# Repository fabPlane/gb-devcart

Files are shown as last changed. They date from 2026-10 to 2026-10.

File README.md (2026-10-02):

# GB DEVCART r1.1 — open hardware

A simple, original Game Boy (DMG) / ModRetro Chromatic homebrew development cartridge.
512 KB of rewritable NOR flash, 8 KB of battery-free F-RAM, and an MBC5-subset mapper built
from discrete 74HC logic. 2-layer, 1.0 mm, 32 edge fingers at 1.5 mm pitch, 5 V bus. The board uses the
standard Game Boy cartridge outline (51.4 × 61 mm, finger tongue, lock notch, shell screw and post holes), so it
fits a DMG / GBC / Pocket / ModRetro Chromatic cartridge shell; see [`mech/`](mech/) and the fit check.

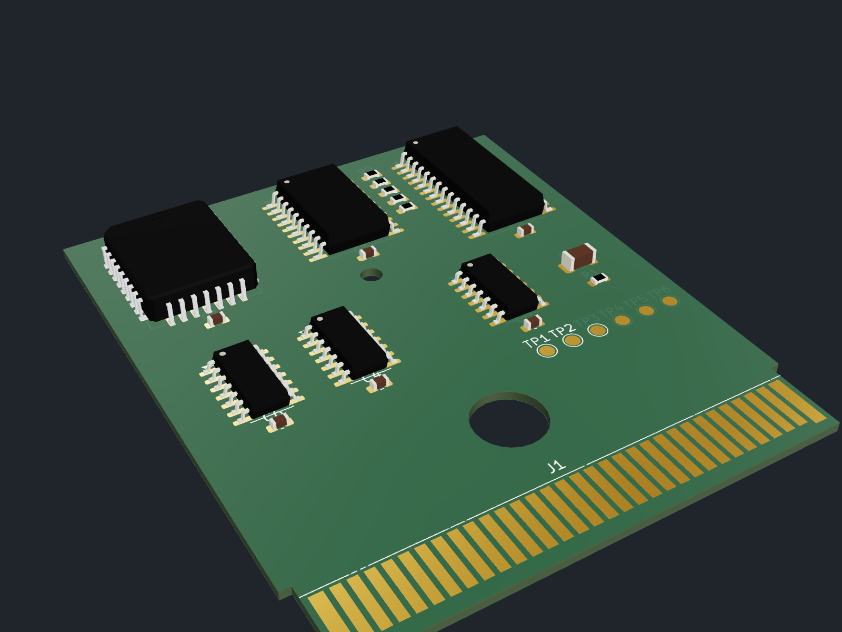
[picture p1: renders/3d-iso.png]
GB DEVCART r1, 3D render


> **r1 (56 × 49.5 mm) did not fit a cartridge shell; do not order it.** r1.1 is the same circuit on the
> DMG outline.
>
> **Status:** fully routed (2 layers, Freerouting through fabdesk), DRC clean, in-stock JLCPCB parts
> with LCSC numbers, JLC gerbers/BOM/CPL in `exports/jlcpcb/`. **Not yet built or tested on hardware.**

**r2.1** (FPGA mapper, 8 MB flash, USB-C programming, 4 layers) is in [`r2/board/`](r2/board/README.md);
both boards are checked against a 3D cartridge shell model in [`mech/`](mech/).

Designed with [fabPlane](https://fabplane.com) (fabdesk) driving Claude Code. Inspired by the ModRetro
"Demo Cartridge", but an original, much simpler design: no FPGA, no level shifters, no regulators.

| What | Where |
| --- | --- |
| KiCad project (schematic, board, custom symbols/footprint) | `board.kicad_*`, `lib/`, `circuit.netlist.json` |
| 3D models of every part, 3D renders, STEP of the whole board | `3dmodels/`, `renders/`, `exports/board.step` |
| USB programmer (Arduino Mega firmware + PC tool + cart simulator) | [`programmer/`](programmer/README.md) |
| Demo homebrew game "Bit Catcher" (GBDK-2020) | [`game/`](game/README.md) |
| JLCPCB / LCSC price list | [`docs/jlcpcb-pricing.md`](docs/jlcpcb-pricing.md) |

## Quick start

```bash
# build the demo game (GBDK-2020)
make -C game GBDK_HOME=/path/to/gbdk
# test the programmer end to end against the cart simulator (no hardware needed)
programmer/test_e2e.sh
# flash a real cart through an Arduino Mega 2560 (see programmer/README.md for wiring)
python3 programmer/host/gbflash.py --port /dev/ttyACM0 flash game/dist/bitcatcher.gb
```

| Top | Bit Catcher on the cart |
| --- | --- |
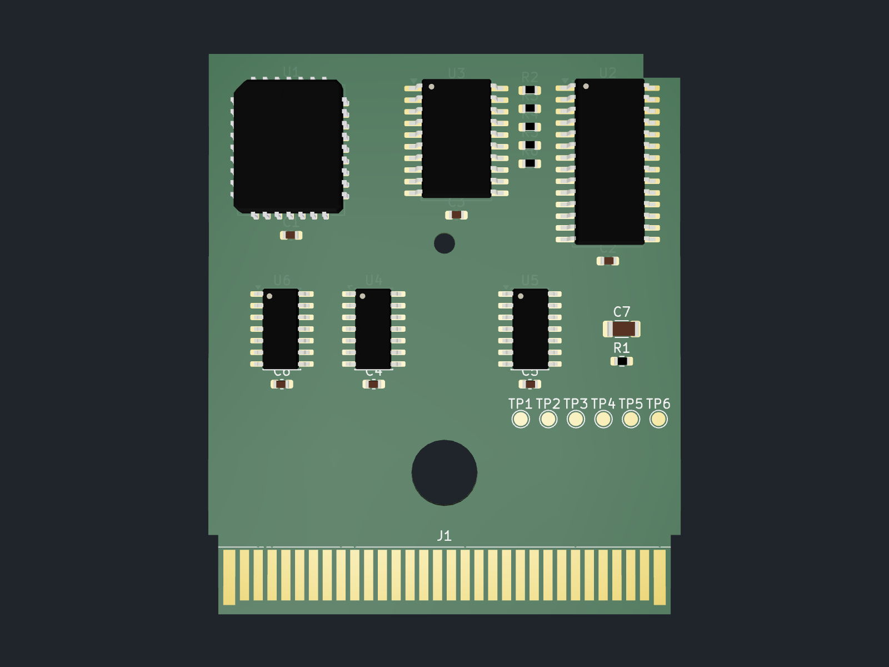
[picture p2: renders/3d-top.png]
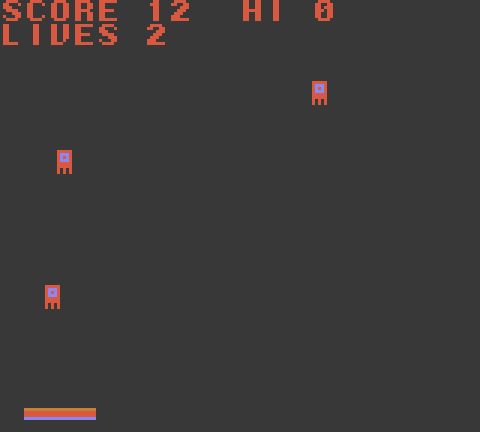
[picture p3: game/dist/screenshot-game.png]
game
|  |  |

## Memory map

| GB address | Access | Function |
| --- | --- | --- |
| 0x0000–0x3FFF | R | ROM bank 0 (fixed): flash 0x00000–0x03FFF |
| 0x4000–0x7FFF | R/W | ROM bank N (switchable): flash `N*0x4000 + (addr & 0x3FFF)`, N = 0–31 |
| 0x2000–0x2FFF | W | Bank register (74HC574, bits 0–4 used, bits 5–7 latched but unconnected) |
| 0xA000–0xBFFF | R/W | 8 KB F-RAM (FM18W08, A13/A14 tied low), always enabled |

Notes:
- 0x3000–0x3FFF is deliberately **not** decoded, so MBC5 software that writes bit 8 there does not clobber the bank register.
- No RAM-enable register and no RAM bank latch. Upgrade path: use the FRAM's A13/A14 with a 2-bit latch.
- The bank register is undefined at power-up. Bank-0 code must write it before using 0x4000–0x7FFF.
- Writes to 0x4000–0x7FFF are the only ones that reach the flash /WE.

## Logic

| Signal | Equation |
| --- | --- |
| Flash /CE | `A15` |
| Flash /OE, FRAM /OE | `/RD` |
| Flash /WE | `/WR | A15 | /A14` (U5) |
| Latch clock (rising edge latches) | `/WR | A15 | A14 | A12 | /A13` (U4, U6) |
| Latch /OE | `/A14`; outputs are pulled down (2.2 kΩ), so A14=0 gives bank 0 |
| FRAM /CE | `/CS | A14 | /A13` (U5, U6) |
| FRAM /WE | `/WR` |

The flash sees `A0–A13` from the bus and `A14–A18` from the latch (`D0–D4`).

## Flashing from the Game Boy

Run the flasher from WRAM/HRAM, because the flash returns status instead of data while busy.
Interrupts off. All command cycles go through the switchable window, so bank-register writes at
0x2000 never reach the flash.

The SST39SF040 decodes commands on address bits A14–A0 only: `0x5555` and `0x2AAA`.
- `0x5555` needs chip A14 = 1, so select an **odd** bank (e.g. 1) and write to GB `0x5555`.
- `0x2AAA` needs chip A14 = 0, so select an **even** bank (e.g. 0) and write to GB `0x6AAA`.

Byte program of `data` to chip address `X`:
1. `[0x2000]=1;  [0x5555]=0xAA`
2. `[0x2000]=0;  [0x6AAA]=0x55`
3. `[0x2000]=1;  [0x5555]=0xA0`
4. `[0x2000]=X>>14;  [0x4000 + (X & 0x3FFF)]=data`
5. Poll the same address until DQ7 equals data bit 7 (or DQ6 stops toggling), about 20 µs.

Sector erase (4 KB) at `SA`: the same first two cycles, then `[0x2000]=1; [0x5555]=0x80`,
`[0x5555]=0xAA`, `[0x2000]=0; [0x6AAA]=0x55`, then `[0x2000]=SA>>14; [0x4000+(SA&0x3FFF)]=0x30`.
Chip erase: the same, with the last cycle `[0x2000]=1; [0x5555]=0x10`. Then poll as above.

Program a 16 KB bank only from a bank other than the one being written, or from RAM, and verify by
read-back. Keep bank 0 (vectors, header, flasher stub) write-protected by software convention.

## Hardware notes

- `/RESET` has a 10 kΩ pull-up (R1). `AUDIO_IN` is unconnected except for test pad TP6.
- Test pads: TP1 VCC, TP2 GND, TP3 CLK, TP4 /WR, TP5 /RD, TP6 AUDIO_IN.
- Edge fingers (`gbdev:GB_Cart_Edge_32_DMG`) are on the component side and start 1.5 mm above the board edge (VCC/GND 1.0 mm, so they make contact first); order the board with ENIG or hard gold.
- Pin 1 (VCC) is at the left, looking at the component side. Order: VCC, CLK, /WR, /RD, /CS, A0–A15, D0–D7, /RESET, AUDIO_IN, GND.
- Shell holes: Ø7.2 at (25.7, 45.65) for the screw tube and Ø2.3 at (25.7, 20.65) for the locating post (mm from the
  top-left, KiCad frame), each with a copper keep-out. Parts stay inside the shell's component zone (x 0.55–50.85,
  y 0.9–51.2); nothing on the back.
- The PLCC-32 flash is 3.56 mm tall. An OEM shell has about 3.6 mm of room on the label side (gekkio's GB-CART boards
  use the same package); the printed shell in `mech/` has 3.3 mm, so set `front_inner_z` to 6.1 in `mech/dims.py` before printing one for r1.1.
- Latch outputs are tri-stated and pulled down for bank 0, so the bank-0 address-to-data path depends on a ~2.2 kΩ RC settle (about 40–80 ns). Check the timing on a real console.
- The `/CS` decode assumes `/CS` is asserted for A15 = 1; verify on the target hardware.
- Bus is 5 V logic (HC family). Confirm that your target's cartridge port tolerates 5 V.

## BOM

| Ref | Qty | Value | Package | Suggested MPN |
| --- | --- | ----- | --- | --- |
| U1 | 1 | 512 KB 5 V NOR flash | PLCC-32 | SST39SF040-70-4C-NHE |
| U2 | 1 | 32 KB F-RAM | SOIC-28W | FM18W08-SG |
| U3 | 1 | 74HC574 | SOIC-20W | SN74HC574DWR |
| U4, U5 | 2 | 74HC32 | SOIC-14 | SN74HC32DR |
| U6 | 1 | 74HC00 | SOIC-14 | SN74HC00DR |
| C1–C6 | 6 | 100 nF X7R | 0603 | — |
| C7 | 1 | 10 µF X5R | 1206 | — |
| R1 | 1 | 10 kΩ | 0603 | — |
| R2–R6 | 5 | 2.2 kΩ | 0603 | — |
| TP1–TP6 | 6 | test pad D1.5 mm | — | — |
| J1 | 1 | edge fingers (PCB feature) | `gbdev:GB_Cart_Edge_32` | — |

## Programming over USB

The cart is programmed by an **Arduino Mega 2560** (5 V I/O, so no level shifters) wired to a
32-pin Game Boy cartridge slot. The PC runs `programmer/host/gbflash.py`
(`info`, `flash`, `dump`, `erase`, `save-backup`, `save-restore`). The flashing algorithm lives in
`programmer/firmware/gbflash/gbflash_core.h`, which also compiles into a native simulator of this
cart for hardware-free tests. See [`programmer/README.md`](programmer/README.md) for the wiring table.

## 3D models

Every component carries a 3D model, vendored in `3dmodels/` and referenced as
`${KIPRJMOD}/3dmodels/…`, so the project renders and exports (STEP/GLB) with no global KiCad
3D library. The passives and SOIC models come from the official KiCad 3D library
(CC-BY-SA 4.0 with the KiCad library exception). KiCad ships no PLCC-32 model, so
`scripts/make_plcc32_model.py` generates one with CadQuery (JEDEC MS-016 body, 32 J-leads)
matching the KiCad footprint. Regenerate the renders with:

```bash
kicad-cli pcb export glb --include-pads --include-silkscreen --include-soldermask -o renders/board.glb board.kicad_pcb
kicad-cli pcb export step -o exports/board.step board.kicad_pcb
cd scripts/render3d && npm install && CHROMIUM_PATH=/path/to/chrome npm run render  # -> renders/3d-*.png
```

## Ordering

See [`docs/jlcpcb-pricing.md`](docs/jlcpcb-pricing.md) for bare-PCB and assembled prices at
JLCPCB with LCSC part numbers. Order ENIG (or hard-gold fingers with a 45° bevel) and **1.0 mm**
thickness so the board fits a standard DMG cartridge shell.

JLC order files (regenerate with `KICAD_CLI=… python3 scripts/jlc_export.py`):

| File | Upload as |
| --- | --- |
| `exports/jlcpcb/gerbers.zip` | Gerber files (2 layers, 51.4 × 61 mm DMG outline, 1.0 mm) |
| `exports/jlcpcb/bom.csv` | Assembly BOM: 9 lines, every line with an LCSC part number |
| `exports/jlcpcb/cpl.csv` | Assembly pick-and-place (19 parts, top side) |

Check the rotation preview on JLC's assembly page before confirming. SOIC and PLCC reels
sometimes need a ±90° correction.

| Routed top (F.Cu) | Routed bottom (B.Cu) |
| --- | --- |
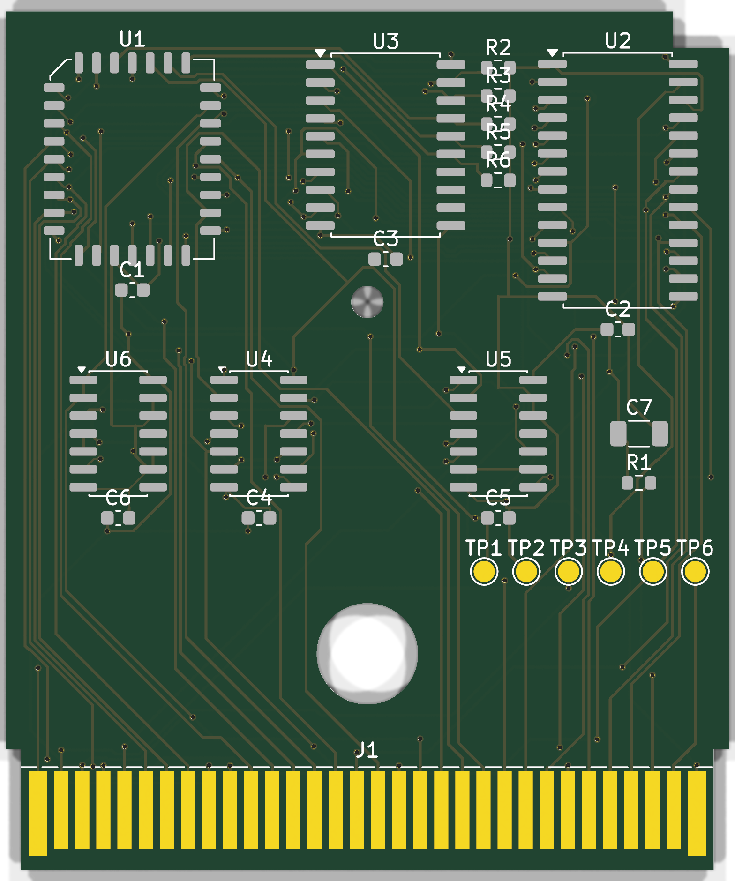
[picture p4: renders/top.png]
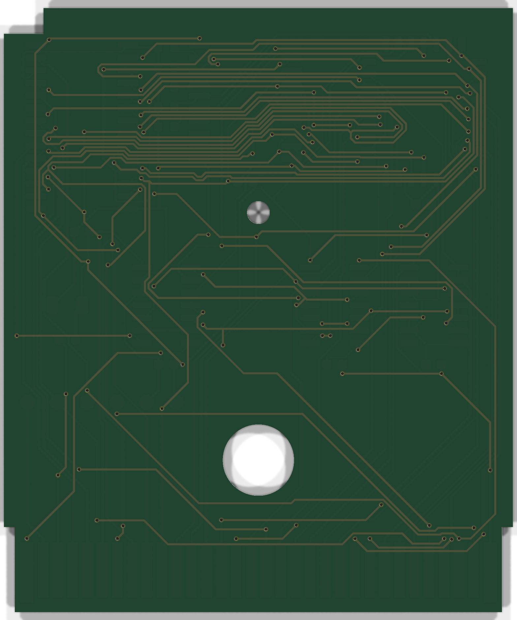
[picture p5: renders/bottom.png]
bottom
|  |  |

Snapshot from 2026-10-01 for the r1 board (USD, before shipping; r1.1 is a similar size, so expect similar prices):

| Qty | Bare PCB, ENIG | PCB + Economic assembly |
| --- | --- | --- |
| 5 | $18.60 ($3.72/board) | ~$129 (~$25.75/board) |
| 10 | $21.60 ($2.16/board) | ~$215 (~$21.46/board) |
| 30 | $28.90 ($0.96/board) | ~$496 (~$16.55/board) |
| 100 | $62.70 ($0.63/board) | ~$1,497 (~$14.97/board) |

Before ordering:
- **Stock.** The design now uses the in-stock drop-ins: SST39SF040-55-4I-NHE-T (C632847, the same flash
  in a faster, industrial grade) and FM18W08-SGTR (C55945, the same F-RAM on tape and reel). Stock was
  17 and 45 on 2026-10-01, so re-check it before ordering. The F-RAM is about 60% of the assembled cost.
- **Gold-finger size rule.** JLC's bevelled gold-finger option needs boards of at least 50 mm on both sides;
  r1.1 is 51.4 × 61 mm, so it qualifies. Plain ENIG needs no change.

## Project files

- `scripts/sync_fields.py` copies MPN / Manufacturer / LCSC from the netlist into `board.kicad_pcb` and `board.kicad_sch`.
- `scripts/jlc_export.py` writes the JLC gerbers, BOM and CPL.
- `scripts/gen.py` generates `lib/gbdev.kicad_sym`, `lib/gbdev.pretty/` and `circuit.netlist.json`. The netlist is the source of truth; `board.kicad_*` are built from it.
- Symbols and the edge footprint are custom (`gbdev` library) because the build environment has no KiCad symbol libraries.

## Project status

- **Netlist:** 26 components, 46 nets. Custom `gbdev` symbols and edge footprint; r1.1 placement on the DMG outline
  (`scripts/gen.py`, checked by `r2/hw/layout_dmg.py`), all parts inside the shell's component zone.
- **Routing:** done with Freerouting 2.4.1 (Java 25) through fabdesk's `route_run`. All 134 connections are routed
  in one run.
  - **Rules:** 0.2 mm tracks (Freerouting necks down to 0.15 mm at some pads; the board minimum is 0.15 mm),
    0.15 mm clearance, 0.5/0.3 mm vias, all within JLCPCB's standard 2-layer process.
  - **Keepouts:** copper keep-outs 0.5 mm around both shell holes.
- **DRC (r1.1):** 0 errors, 0 unconnected; 19 silkscreen warnings (overlapping reference text).
- **Fit check:** `python3 mech/fit_check.py r1=board.kicad_pcb` passes every check; one warning for the PLCC-32 height.
- **What didn't work:** fabdesk's built-in `capacity` router (fab_router) could not route this dense
  2-layer bus. Its best result was 63 of 134 connections, and long runs block the bridge process until
  fabdesk times out. To get to the result above, parts were moved (U2, U3, C2, C3, C6, R2–R6), the rules
  were tightened as listed, and Freerouting was enabled.
- **Board thickness:** 1.0 mm in the file. Choose 1.0 mm in the fab order too.
- **Not yet verified on hardware:** bus timing (bank-0 pull-down settling), the `/CS` decode assumption,
  and the JLC rotation offsets.

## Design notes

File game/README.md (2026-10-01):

# Bit Catcher

A tiny homebrew game for the GB DEVCART r1, written in C with
[GBDK-2020](https://github.com/gbdk-2020/gbdk-2020). Catch the falling cartridges, dodge the bugs.
Missing a cartridge or catching a bug costs a life. The speed goes up every 8 catches, and the
high score is kept in the cart's F-RAM, so it survives power-off without a battery.

| Title | In game | Game over |
| --- | --- | --- |
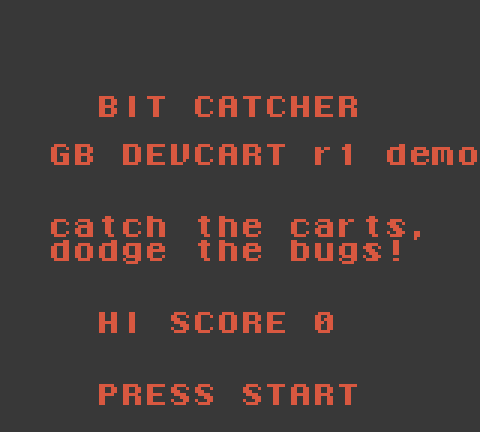
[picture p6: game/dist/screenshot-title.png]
title
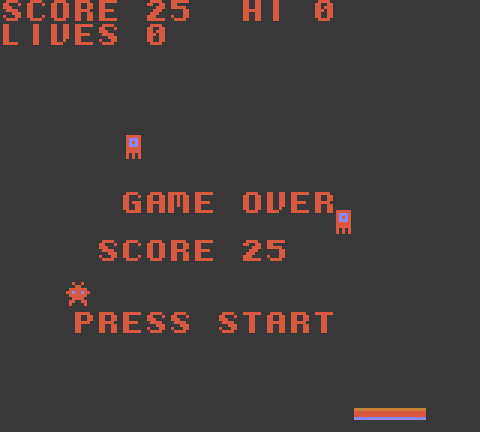
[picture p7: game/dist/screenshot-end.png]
end
|  | game |  |

## Build

```bash
# GBDK-2020 4.x: download gbdk-linux64.tar.gz (or the macOS/Windows build) and unpack it
make GBDK_HOME=/path/to/gbdk          # -> dist/bitcatcher.gb (32 KB)
```

The ROM header says MBC5 + RAM + battery (`0x1B`), 32 KB ROM and 8 KB RAM. The devcart uses
the same bank register (`0x2000`) and RAM window (`0xA000`), so the ROM runs unchanged in
emulators (BGB, SameBoy, mGBA, PyBoy) and on the cart. It is also flagged CGB-compatible, so it
runs on a Game Boy Color or ModRetro Chromatic.

## Devcart-specific details

- **Bank latch at boot.** The 74HC574 bank latch powers up with random contents, so `main()`
  writes `1` to `0x2000` first. All of the game's code and data sits in bank 0 (below `0x1600`,
  see `build/bitcatcher.map`), so nothing runs from the switchable window before that write.
- **Saves.** The high score is stored as `"GBDC"` plus a 16-bit value at `0xA000`. On the
  devcart the F-RAM is always enabled; the `ENABLE_RAM` write to `0x0000` is only there for
  emulators.

## Test

```bash
pip install pyboy
python3 test_pyboy.py   # boots headless, plays with a simple bot, checks the high score persists
```

## Put it on the cart

```bash
python3 ../programmer/host/gbflash.py --port /dev/ttyACM0 flash dist/bitcatcher.gb
```

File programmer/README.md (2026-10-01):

# USB programmer

The devcart has no USB of its own. Its bus is the Game Boy's 5 V parallel bus, so the cheapest
and simplest programmer is a 5 V microcontroller with enough pins to *be* the Game Boy: an
**Arduino Mega 2560** (or clone, ~US$15), which has native 5 V I/O, 70 GPIOs and a USB-serial
bridge. You need no level shifters and no extra board.

```
PC ──USB── Arduino Mega 2560 ──27 wires── GB cartridge slot ── GB DEVCART r1
           (gbflash.ino)                   (32-pin, 1.5 mm)
```

| Path | What |
| --- | --- |
| `firmware/gbflash/gbflash.ino` | Mega sketch: bus timing on raw AVR ports, 1 Mbaud serial |
| `firmware/gbflash/gbflash_core.h` | Protocol + SST39SF040 algorithms, hardware independent |
| `host/gbflash.py` | PC tool: `info`, `flash`, `dump`, `erase`, `save-backup`, `save-restore` |
| `sim/cart_sim.cpp` | Native model of this cart (glue logic, flash, F-RAM) running the same core |
| `test_e2e.sh` | Flashes, dumps and verifies ROMs and saves against the simulator |

## Parts

- Arduino Mega 2560 R3 (or a clone with a CH340 USB chip; use the CH340 driver on macOS/Windows).
- A 32-pin, 1.5 mm pitch Game Boy cartridge slot. Replacement DMG slots sell for a few dollars
  (search "Game Boy DMG cartridge slot 32 pin"). Solder wires to its pins, or plug the devcart's
  fingers into it.
- 27 jumper wires. Keep them under ~20 cm.

## Wiring

Cart pin numbers are counted from the left with the cart's component side facing you
(the order of the devcart's `J1`).

| Cart pin | Signal | Mega pin | AVR port |
| --- | --- | --- | --- |
| 1 | VCC | 5V | — |
| 2 | CLK | not connected | — |
| 3 | /WR | D2 | PE4 |
| 4 | /RD | D3 | PE5 |
| 5 | /CS | D4 | PG5 |
| 6–13 | A0–A7 | D22–D29 | PORTA0–7 |
| 14–21 | A8–A15 | D37, D36, D35, D34, D33, D32, D31, D30 | PORTC0–7 |
| 22–29 | D0–D7 | D49, D48, D47, D46, D45, D44, D43, D42 | PORTL0–7 |
| 30 | /RESET | D5 (held high) | PE3 |
| 31 | AUDIO_IN | not connected | — |
| 32 | GND | GND | — |

## Use it

```bash
# 1. firmware (Arduino IDE: open firmware/gbflash/gbflash.ino, board "Arduino Mega or Mega 2560")
arduino-cli compile --fqbn arduino:avr:mega programmer/firmware/gbflash
arduino-cli upload  --fqbn arduino:avr:mega -p /dev/ttyACM0 programmer/firmware/gbflash

# 2. host tool
pip install pyserial
python3 programmer/host/gbflash.py --port /dev/ttyACM0 info          # expects "0xbf 0xb7 SST39SF040"
python3 programmer/host/gbflash.py --port /dev/ttyACM0 flash game/dist/bitcatcher.gb
python3 programmer/host/gbflash.py --port /dev/ttyACM0 dump  backup.gb --size 32768
python3 programmer/host/gbflash.py --port /dev/ttyACM0 save-backup bitcatcher.sav
```

`flash` erases the whole chip, programs the image in 256-byte chunks (skipping erased `0xFF`
chunks), reads every bank back and compares it with the file, then leaves the bank latch at 1.
Use `--port COM5` on Windows.

## How flashing works on this cart

The SST39SF040's `/WE` is only asserted for writes to `0x4000–0x7FFF`, and its address lines
A14–A18 come from the bank latch (written at `0x2000`). Every JEDEC command cycle therefore goes
through the switchable window:

| Flash address | Bank latch | CPU address |
| --- | --- | --- |
| `0x5555` | 1 (odd) | `0x5555` |
| `0x2AAA` | 0 (even) | `0x6AAA` |
| byte at flash `fa` | `fa >> 14` | `0x4000 + (fa & 0x3FFF)` |

Byte program = `AA@5555, 55@2AAA, A0@5555, data@fa`, then Data# polling on DQ7 (≤ 20 µs).
Chip erase = `AA, 55, 80, AA, 55, 10@5555` (≤ 100 ms). The bank-register writes at `0x2000`
never reach the flash (its `/WE` stays high), so they can sit between command cycles safely.
`gbflash_core.h` implements exactly this, and the same sequences work from Game Boy code running
in WRAM if you want to flash from the console itself.

## Test without hardware

```bash
programmer/test_e2e.sh   # needs a C++17 compiler and python3
```

This builds `sim/cart_sim` from the same `gbflash_core.h` the Mega runs, against a model of the
cart taken from `circuit.netlist.json`: the 74HC32/74HC00 decode, a 74HC574 latch that powers up
random, 2.2 kΩ pull-downs, an SST39SF040 command state machine with Data# polling and 1→0-only
programming, and the 8 KB F-RAM window. It flashes the game onto a cart full of random data,
flashes and dumps a 512 KB image with different data in each of the 32 banks, and round-trips an
F-RAM save. The test found one bug while it was being written: the model wrongly treated a `0xF0`
data byte as the flash's reset command.

**Not yet tested on real hardware.** Bus timing on the Mega has a wide margin (250 ns or more per
strobe against 70 ns parts), but long wires can ring, so keep them short.

## Alternatives

- **Flash from the Game Boy itself:** copy a small flasher into WRAM and run the same command
  sequences. You still need a way to get the data in, such as the link cable or a second cart.
- **Existing cart flashers** such as insideGadgets' GBxCart RW with FlashGBX may work with a
  custom cartridge profile that matches the bank-1/bank-0 command addresses above. This is
  untested.
- **Native USB (r2 idea):** an RP2040 with 74LVC245 level shifters, either on the cart (as on
  the ModRetro board) or as a slot-style dock.

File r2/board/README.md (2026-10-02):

# GB DEVCART r2.1 — FPGA mapper + USB-C board

A Game Boy / ModRetro Chromatic dev cart with a Gowin GW1N-LV4 FPGA as the mapper (MBC5 + locked dev
mode, `r2/rtl/`), 8 MB S29GL064N flash, 32 KB FM28V020 F-RAM, 5 V ↔ 3.3 V bus transceivers, and a
CH347F USB-C bridge. The bridge programs the flash through the FPGA (`programmer/host/gbflash.py --usb`)
and loads the FPGA over JTAG (`openFPGALoader -c ch347_jtag`). Parts and pinouts: `docs/r2-parts.md`.

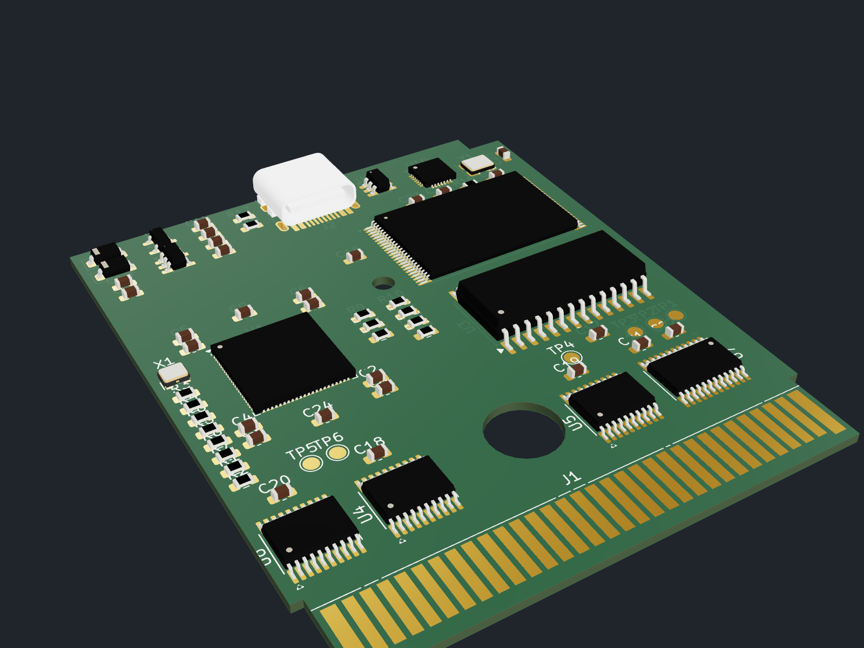
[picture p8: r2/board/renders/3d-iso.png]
r2.1, 3D render


> **Status:** placed and fully routed in fabdesk, DRC clean, fit check passes.
> **Not built or tested on hardware.**

## Board

- Standard DMG cartridge outline: 51.4 × 61 mm, finger tongue, lock notch, Ø7.2 / Ø2.3 shell holes.
  Fits a DMG / GBC / Analogue Pocket / ModRetro Chromatic cartridge shell. The USB-C receptacle needs
  the r2 shell from `mech/` (`shell_back_usb` + `shell_front_usb`), which opens the top wall over it.
- 4 layers, 1.0 mm: F.Cu signals, In1.Cu solid GND plane, In2.Cu 3V3 plane, B.Cu signals. Signals
  were routed on F.Cu and B.Cu only (one RAM_NCE hop on In2.Cu), so both planes stay whole.
- Every part on the label side, inside the shell's component zone; nothing on the back.
- J2 USB-C is centred on the top edge, its mouth 1.2 mm past the board edge.
- Rules: 0.15 mm tracks (0.1 mm neck-downs), 0.1 mm clearance (the QFN-88 pads sit 0.1 mm apart),
  0.5 / 0.3 mm vias, 0.2 mm hole clearance. JLCPCB's 4-layer process allows 0.09 mm.

## Results

- `kicad-cli pcb drc --schematic-parity`: 0 errors, 0 unconnected, 0 parity issues. 108 warnings,
  all silkscreen (overlapping or clipped reference text).
- `python3 mech/fit_check.py r2.1=r2/board/board.kicad_pcb`: every check passes.
- 68 parts, 116 nets, 2 planes, about 120 plane vias. Freerouting routed all 181 signal connections.

## How it was built

1. `r2/hw/gen_r2.py` writes `circuit.netlist.json` with the DMG outline, shell holes and placement
   from `r2/hw/layout_dmg.py`. That file also checks the placement: no courtyard overlaps, everything in
   the shell zone, clear of the notch and the holes.
2. fabdesk `circuit_build`, then `circuit_place` for the rotations.
3. `r2/hw/power_vias.py`: a via next to every GND / 3V3 pad (a via grid in the QFN exposed pads), plus
   the In1 / In2 planes, through fabdesk's `native_edit_transaction`.
4. Copper keep-outs around the shell holes and the USB-C pegs (`fab_api.hole_keepouts`).
5. fabdesk `route_run` with Freerouting on the signal nets, restricted to F.Cu and B.Cu
   (`settings: {layers: [3, 34]}`), then a few local fixes: ground hops into the FPGA's exposed pad,
   RAM_NCE re-routed with In2 allowed.
6. Planes refilled with 0.3 mm thermal spokes; DRC with `kicad-cli`.

## Order files

`exports/jlcpcb/` (regenerate with `KICAD_CLI=… BOARD_DIR=r2/board python3 scripts/jlc_export.py`):

| File | Upload as |
| --- | --- |
| `gerbers.zip` | Gerbers, 4 layers, 1.0 mm, 51.4 × 61 mm |
| `bom.csv` | Assembly BOM, 21 lines with LCSC numbers |
| `cpl.csv` | Pick and place, 61 parts, top side |

Order ENIG or hard-gold fingers. Check the rotation preview on JLC's assembly page.

3D models: the parts use KiCad's library models, vendored in `../../3dmodels/`. KiCad has none for the
HRO TYPE-C-31-M-12, so `scripts/make_usbc_model.py` generates a simplified one. The 2.5 × 2.0 mm
oscillator uses the Epson SG210 model, which has the same package.

| Top | Bottom |
| --- | --- |
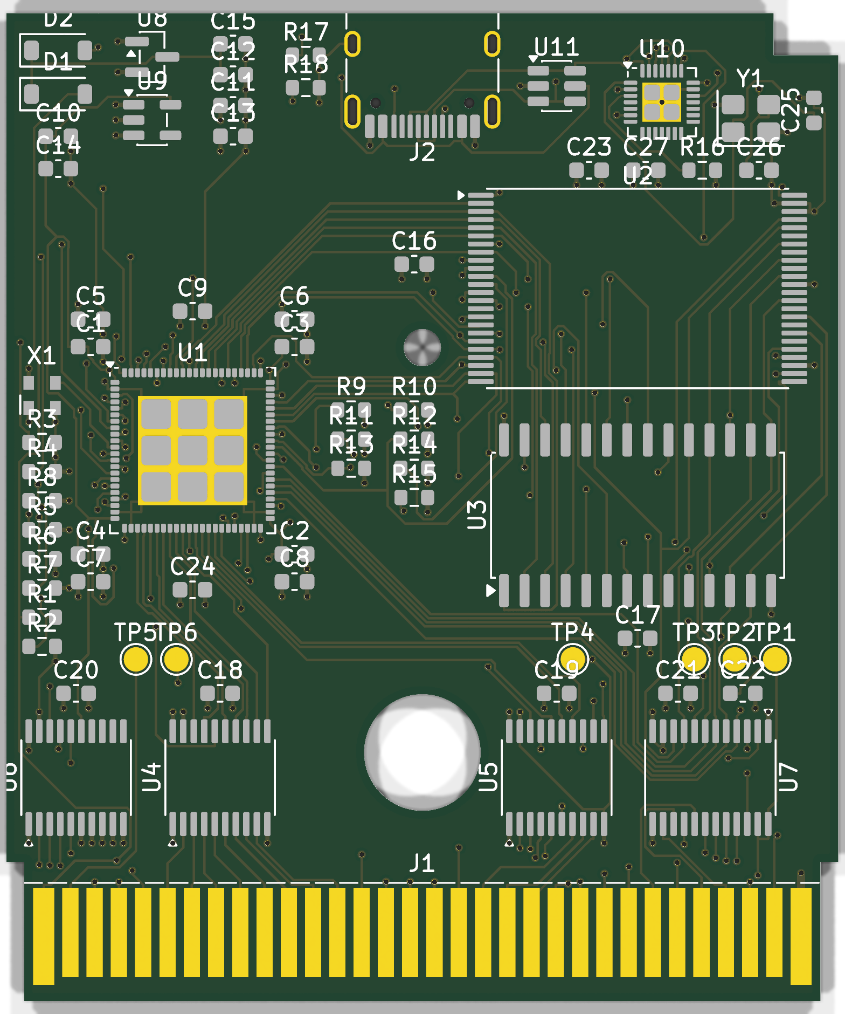
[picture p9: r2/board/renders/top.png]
top
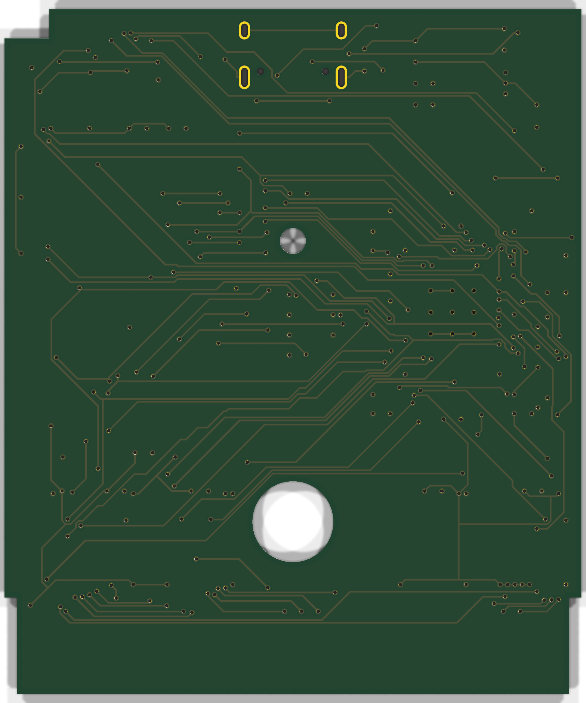
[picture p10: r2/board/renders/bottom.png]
bottom
|  |  |

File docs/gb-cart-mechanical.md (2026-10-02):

# Game Boy (DMG/GBC) cartridge: mechanical reference

Research date 2026-10-02. All values are in mm. Confidence key:
**CAD** means measured by me from open CAD files (KiCad Edge.Cuts/pads parsed, or STL ray-cast with trimesh).
**doc** means a published spec. **forum** means a secondary or unverified source.
No Nintendo drawing of the shell or PCB was found in public. Every shell number comes from community replicas, so check them against a real cart before tooling.

## Sources

| Key | Source | Licence |
| --- | --- | --- |
| GK | gekkio/gb-hardware: GB-CART32K-A, GB-CART256K-A, GB-MBCTEST and GB-LIVE32 `.kicad_pcb` files, plus the README spec lines. https://github.com/Gekkio/gb-hardware | CC BY 4.0 |
| MBL | MouseBiteLabs/Game-Boy-Cartridges, `MBC5 (Type A, SRAM)/mbc5_SRAM_typeA_1-2.kicad_pcb` (footprint `GBC_CART_TABBED`; the README says the shape "mimic[s] original Game Boy circuit boards"). https://github.com/MouseBiteLabs/Game-Boy-Cartridges | CC BY-SA 4.0 |
| RGR | RetroGameRevival, "Nintendo GameBoy (classic/DMG-01) cartridge shell". Both STLs are in assembled position. https://www.printables.com/model/804399 | CC BY-NC |
| FUN | FuniverseMN, "Gameboy DMG Cartridge Shell". The maker test-fit it in a real DMG with a Link's Awakening board. https://www.printables.com/model/281341 | CC BY-SA |
| WOOD | Staacks/wooden-game-boy-cartridge: CNC G-code (1.5 mm end mill; outline = toolpath extent − 1.5). https://github.com/Staacks/wooden-game-boy-cartridge | CC BY 4.0 |
| WP | Wikipedia, "Game Boy Game Pak". https://en.wikipedia.org/wiki/Game_Boy_Game_Pak | doc |
| LEM | Lemmy "Game Cartridge Dimensions" table (a repost). https://lemmy.world/post/241714 | forum |

## 1. Outer shell (grey DMG Game Pak)

| Item | Value | Source | Confidence |
| --- | --- | --- | --- |
| Width | 57.0 (FUN 56.95, WOOD 56.8) | WP 57; RGR; FUN; WOOD | doc + CAD, consistent |
| Height | 65.0 (RGR); 65.05 (FUN); 65.5 (WP); 64.5 (WOOD) | as listed | sources disagree by up to 1.0. Use 65.0 to 65.5 |
| Thickness | 7.8 (RGR assembled); 7.5 (WP; LEM "GB"); 9 (LEM "GBC", probably measured over the label bump) | RGR, WP, LEM | sources disagree. Design to ≤ 7.8 |
| Half thicknesses | back 5.75, front 5.3, overlapping at the lip (RGR); back 5.8, front 5.2 (FUN); back "about 5.5" (WOOD) | RGR, FUN, WOOD | CAD |
| Outline corner radii | ≈1.0 on all four corners (RGR silhouette); top corners ≈1.0 (FUN) | RGR, FUN | CAD |
| Lock notch (top-right seen from the label side; the DMG power-switch tab slides into it) | 4.8 wide × 3.3 deep (RGR); 5.0 wide × 3.0 deep (FUN) | RGR, FUN | CAD. Sources disagree by about 0.3 |
| Label recess (front) | ≈44.0 wide × ≈35.5 tall × 0.35 deep (RGR); the side rails beside it are at full height | RGR | CAD. Confirm on a real cart |
| Top front finger scoop | concave, ≈12 tall, up to 0.94 deep, ending about 15 below the top edge | RGR | CAD |
| Side grip grooves | 5 grooves at 2.0 pitch, 0.47 deep, on both sides, about 4 to 14 below the top | RGR | CAD |
| Front edge chamfer | ≈1.6 × 0.3 along the long sides | RGR | CAD (rough) |

## 2. PCB (fingers at the bottom, origin at the PCB bottom-left, component/finger side facing you)

| Item | GK (GB-CART*) | MBL (MBC5 Type A) | Confidence |
| --- | --- | --- | --- |
| Thickness | 1.0 (README "PCB thickness: 1.0mm"; board stack-up 1.0) | 0.8 ("Thickness: 0.8mm", "Be sure to get them in 0.8mm") | doc. Sources disagree. Other repro boards (OSH Park listings) also say 0.8 |
| Body width × height | 51.4 × 61.0 | 51.0 × 61.0, or 53.0 × 62.0 over the anti-rotation tabs | CAD |
| Finger tongue | X 1.1–50.3 (49.2 wide), 8.6 tall, bottom corners R0.9 | X 0.75–50.25 (49.5 wide), 9.0 tall, bottom corners R1.5 | CAD |
| Shoulder (tongue to body) | 1.1 step on each side at Y = 8.6, R0.5 corners | 0.75 step at Y = 9.0 | CAD |
| Top-right notch | X 47.4–51.4 (4.0 wide), Y 58.4–61.0 (2.6 deep), R0.5 | X 46.0–51.0 (5.0 wide), Y 58.0–61.0 (3.0 deep) | CAD. Sources disagree |
| Big hole (the shell's screw tube passes through it) | Ø7.2 NPTH at (25.7, 15.35) | Ø7.25 at (25.5, 15.80) | CAD |
| Small locating hole | Ø2.3 at (25.7, 40.35) | Ø2.25 at (25.5, 40.80) | CAD |
| Hole spacing | 25.0 | 25.0 | CAD, consistent |
| Side tabs | none | +1.0 per side, 3.0 tall, at Y 19.2–22.2 and Y 43.2–46.2. MBL added them so the board cannot rotate in loose aftermarket shells. Top tabs are +1.0 at X 13–16 and X 34.8–37.8 | CAD + README |

Holes are on the PCB centreline in both designs (X = half the body width).

## 3. Internal clearance (RGR assembled shell)

The front (label) half carries a perimeter frame of ribs whose underside sits 2.5 above the back outer face. That frame clamps the PCB's **front** face, and the PCB rests on the back half's screw tube and post. Components and fingers face the **label** side. This matches GK/MBL, where parts and fingers share F.Cu.

| Item | Value | Confidence |
| --- | --- | --- |
| Back wall | 1.15 thick (FUN 1.3) | CAD |
| Front wall | 1.65 under the label recess, 2.0 at the rails | CAD |
| PCB front-face plane | 2.5 above the back outer face | CAD |
| Space behind the PCB (back side) | 2.5 − t − 1.15, which is **0.55** for a 0.8 board and **0.35** for a 1.0 board. Treat the back as flat: no parts | CAD |
| Space in front of the PCB (label side), main area | **3.3** (inner face at 5.8) | CAD |
| Space in front, inside the connector mouth (lowest ≈10 of the cart) | 3.95 (inner face at 6.45). The console connector occupies this, so no parts there | CAD |
| Component zone on the front | ≈50.3 wide between the side ribs (1.45 wide each), and lengthwise between the cross ribs, about 11.4 and 61.7 up from the shell's bottom end | CAD |
| Cavity at PCB level | 53.2 wide (± 26.6) × ≈64 long | CAD |
| Tall parts | GK fits a PLCC-32 (JEDEC A ≤ 3.56) on a 1.0 board in a DMG shell. That is more than RGR's 3.3, so an OEM shell probably has about 3.6 of room. Keep parts ≤ 3.3 for printed shells | conflict (CAD vs. working design) |

## 4. Edge connector and slot

| Item | Value | Source | Confidence |
| --- | --- | --- | --- |
| Contacts / pitch | 32 / 1.5, on one side only (the label/component side) | GK, MBL footprints; Pan Docs https://gbdev.io/pandocs/External_Connectors.html | CAD + doc |
| Finger size, pins 2–31 | 1.0 × 5.5 (GK) or 1.0 × 5.4 (MBL) | GK, MBL | CAD |
| Finger size, pins 1 and 32 (GND/VCC) | 1.3 × 6.0 (GK) or 1.5 × 5.6 (MBL) | GK, MBL | CAD |
| Finger gap from the PCB bottom edge | 1.5 (GK) or 1.6 (MBL) for pins 2–31. Pins 1/32 run 0.5 (GK) or 0.2 (MBL) closer to the edge, so they make contact first. The top end of every finger is 7.0 above the edge in both designs | GK, MBL | CAD |
| Pin X positions | pin 1 at X 2.3 (GK) or 2.0 (MBL); pin 2 at 3.95 or 3.75; then 1.5 steps to pin 31; pin 32 is mirrored | GK, MBL | CAD |
| PCB bottom edge to shell bottom opening | 1.15 to 1.6 inset (RGR boss at 16.95 above the shell end, minus the hole height of 15.35 to 15.8); 0.7 to 1.15 (FUN boss at 16.5) | RGR, FUN with GK, MBL | CAD (derived) |
| Shell opening at the connector end | 53.2 wide; 3.95 from the PCB face to the front inner wall; up to ≈10 deep before the first cross rib. On the back side, a 0.75-long lip (49 wide) rises to 2.0 under the PCB edge | RGR | CAD |
| DMG slot connector body | ≈64.3 long × 21.2 deep, or 76.9 including the mounting ears (GB-BRK-SLOT-A footprint `GameBoy_Cartridge_DMG_1x32_P1.50mm_Socket_Horizontal`, F.Fab) | GK | CAD |
| How deep the cart goes into the DMG/GBC, and the slot's opening size | **Not found** in any primary source. The connector itself engages only the bottom ≈10 of the cart (the shell mouth). Measure a console before relying on this | – | gap |

## 5. Console compatibility

| Console | Accepts DMG-size carts? | Notes | Source / confidence |
| --- | --- | --- | --- |
| DMG / MGB / Light | yes | The DMG's power-switch tab enters the top notch. Clear GBC-only carts omit the notch "to prevent them from being used in the original Game Boy". Black dual-mode carts keep it. **Keep the notch** so a DMG can power on. | WP (doc) |
| Game Boy Color | yes | Same outline; the notch is not needed. | WP (doc) |
| GBA / GBA SP | yes (the cart sticks out) | The GBA's shape switch reads a notch on the bottom-rear corner that only GBA carts have. DMG carts have none, so the GBA starts in GB mode at 5 V. | WP (doc) |
| Analogue Pocket | yes | Native GB/GBC slot. No mechanical tolerance is published. EverDrive carts reportedly fail on newer Pocket revisions (androidauthority.com/everdrive-carts-malfunction-with-analogue-pocket-3677246). | forum |
| ModRetro Chromatic | yes | Plays GB and GBC carts; not GBA (ifixit.com/News/106916). ModRetro's own carts "are real Game Boy cartridges … run in an original Game Boy, Game Boy Color and an Analogue Pocket" (retrododo.com/?p=62610), so they use a standard DMG-size shell. They save to FRAM instead of a battery. The console's own screws are tri-point Y1 (ifixit.com/Device/ModRetro_Chromatic). No published slot-depth spec. | doc/forum |

## 6. Shell screw and bosses (RGR CAD unless noted)

| Item | Value | Confidence |
| --- | --- | --- |
| Screw head | 3.8 mm "gamebit" security head (https://handheldlegend.com/products/3-8mm-security-screwdriver-nes-snes-n64-and-game-boy). Not tri-wing, not Phillips | doc (vendor) |
| Screw position | on the centreline, 16.95 above the shell's bottom end (FUN: 16.5) | CAD |
| Back-half screw tube | OD 7.0 (chamfered to 6.0 at the top); top 2.9 above the back outer face; passes through the PCB's Ø7.2 hole | CAD |
| Head counterbore / shank hole | Ø5.0–5.15 from the back face to a depth of 2.25; then Ø2.25 through | CAD |
| Front-half boss | OD 4.0; pilot hole Ø1.5 (Ø2.0 at the mouth, for a self-tapping screw of about 2 mm); hangs from the front inner face (5.8) down to 2.9, about 2.9 tall | CAD |
| Back-half locating post | Ø1.9 tapering to Ø1.3; top 3.15 above the back face; 24.95 above the screw (FUN: 25.3); goes through the PCB's Ø2.3 hole | CAD |
| Screw length / thread | not found. About 2 mm self-tapping, an estimate from the 1.5 pilot | gap |

## 7. Fit check: this repo's `board.kicad_pcb`

These come from parsing `board.kicad_pcb` against the tables above:

- **Width 56.0 does not fit.** The cavity is 53.2 wide, and the OEM-style PCB is 51.4 (51.0 plus tabs to 53.0).
- There is no finger tongue or shoulder step and no top-right notch. A plain 56 × 49.5 rectangle hits the shell's mouth and lock-notch corner.
- Fingers start 0.5 above the board edge; GK/MBL start at 1.5 to 1.6. They are 1.0 × 6.0 at X 28 ± 23.25, so pins 1/32 sit at 4.75/51.25 from the left edge, not GK's 2.3/49.1 on a 51.4 body.
- There is one Ø3.5 hole at (28, 10.5). A DMG shell needs Ø≥7.2 at (W/2, 15.35–15.8) and Ø≥2.3 at (W/2, 40.35–40.8).
- Board thickness is still 1.6 in the file. Order 0.8 (MBL) or 1.0 (GK).
- Height: the PLCC-32 and SOIC-28W parts must stay ≤ 3.3 on the label side. The back side must stay empty (≤ 0.35 to 0.55).
- The simplest fix is to copy GK's GB-CART256K-A Edge.Cuts outline, holes and connector footprint (CC BY 4.0, attribution required).

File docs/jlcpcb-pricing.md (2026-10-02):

# JLCPCB pricing: GB DEVCART r1.1 and r2.1

Snapshot taken **2026-10-02**. USD, before shipping, tax and coupons. Tags:
**[Q]** live JLCPCB quote engine (`cart.jlcpcb.com`, the endpoint the quote page uses);
**[P]** live JLCPCB parts library API; **[F]** JLCPCB's published assembly fee table (help page
"PCB Assembly Cost", 2026-09-09); **[E]** estimate. Prices change, so the real cart decides.

Regenerate: `python3 scripts/jlc_check.py [BOARD_DIR]` (stock, library, prices: writes
`exports/jlcpcb/parts_check.json`), then `python3 scripts/jlc_cost.py …` (writes `cost_estimate.json`).

## Summary

| | r1.1 (parallel flash, 2 layers) | r2.1 (FPGA + USB-C, 4 layers) |
|---|---|---|
| Board | 51.4 × 61 mm, 1.0 mm, ENIG | 51.4 × 61 mm, 1.0 mm, ENIG, 4 layers |
| Parts in JLC's library | 9 / 9 lines, all in stock | 21 / 21 lines, all in stock |
| Unique parts (Extended) | 9 (5) | 21 (11) |
| Solder joints per board | 148 SMT | 423 SMT + 4 THT (USB-C shell legs) |
| **5 boards, assembled** | **≈ $130** ($25.99/board) | **≈ $284** ($56.73/board, Standard) |
| **10 boards, assembled** | **≈ $216** ($21.59/board) | **≈ $443** ($44.28/board, Standard) |
| Most expensive part | FM18W08 F-RAM $9.58 | GW1N-LV4 FPGA $15.79, FM28V020 F-RAM $10.39 |

All part numbers in both BOMs match the design's MPNs, and every line has enough stock for 10 boards.

## r1.1

Bare PCB, 2 layers, 51.4 × 61 mm, 1.0 mm [Q]:

| Finish | 5 | 10 | 30 | 100 |
|---|---|---|---|---|
| HASL (leaded) | $2.00 | $5.00 | $11.50 | $42.80 |
| **ENIG** (recommended for the fingers) | $18.60 | $21.60 | $30.00 | $65.50 |

Parts [P]:

| LCSC | Refs | Package | Library | Stock (2026-10-02) | $/unit at 5 boards |
|---|---|---|---|---|---|
| C14663 | C1, C2, C3, C4, C5, C6 | 0603 | Basic | 54,190,290 | 0.0123 |
| C13585 | C7 | 1206 | Basic | 2,393,834 | 0.2655 |
| C25804 | R1 | 0603 | Basic | 23,046,124 | 0.0018 |
| C4190 | R2, R3, R4, R5, R6 | 0603 | Basic | 7,595,099 | 0.0018 |
| C632847 | U1 | PLCC-32(11.4x14) | Extended | 17 | 5.4574 |
| C55945 | U2 | SOIC-28-300mil | Extended | 45 | 9.5768 |
| C10097 | U3 | SOIC-20-300mil | Extended | 9,077 | 0.5251 |
| C6838 | U4, U5 | SOIC-14 | Extended | 23,625 | 0.2499 |
| C10090 | U6 | SOIC-14 | Extended | 90,183 | 0.1244 |

Order estimate (PCB + parts + assembly fees [F]):

| Boards | Bare PCB (ENIG) [Q] | Parts [P] | **Total, Economic PCBA** | Total, Standard PCBA |
|---|---|---|---|---|
| 5 | $18.60 | $83.90 | **$129.96** ($25.99/board) | $152.44 ($30.49/board) |
| 10 | $21.60 | $164.39 | **$215.85** ($21.59/board) | $238.33 ($23.83/board) |
| 30 | $30.00 | $484.75 | **$554.21** ($18.47/board) | $576.69 ($19.22/board) |
| 100 | $65.50 | $1585.09 | **$1723.65** ($17.24/board) | $1746.13 ($17.46/board) |

- **Stock limit:** only 17 SST39SF040-55 flash chips (C632847) and 45 FM18W08 F-RAMs (C55945) are in
  stock. That covers 10 boards; 30+ boards need JLC Global Sourcing or a pre-order (the 30/100 rows assume list price) [E].
- The board is now ≥ 50 mm on both sides, so JLC's bevelled gold-finger option is allowed.

## r2.1

Bare PCB, 4 layers, 51.4 × 61 mm, 1.0 mm [Q] (JLC's default 4-layer stack-up):

| Finish | 5 | 10 | 30 | 100 |
|---|---|---|---|---|
| HASL (leaded) | $8.00 | $14.00 | $35.10 | $51.70 |
| **ENIG** (recommended for the fingers) | $24.60 | $30.60 | $53.20 | $73.50 |

Parts [P]:

| LCSC | Refs | Package | Library | Stock (2026-10-02) | $/unit at 5 boards |
|---|---|---|---|---|---|
| C19702 | C10, C11, C15 | 0603 | Basic | 10,368,144 | 0.0319 |
| C15849 | C12, C13, C14 | 0603 | Basic | 6,260,435 | 0.0168 |
| C14663 | C1, C2, C3, C4, C5, C6, C7, C8, C9, C16, C17, C18, C19, C20, C21, C22, C23, C24, C27 | 0603 | Basic | 54,190,290 | 0.0123 |
| C1653 | C25, C26 | 0603 | Basic | 2,751,038 | 0.0058 |
| C8598 | D1, D2 | SOD-123 | Basic | 509,945 | 0.0280 |
| C165948 | J2 | SMD | Extended | 436,456 | 0.1857 |
| C25804 | R1, R2, R7, R9, R10, R11, R12, R13, R14, R15, R16 | 0603 | Basic | 23,046,124 | 0.0018 |
| C23186 | R17, R18 | 0603 | Basic | 25,270,096 | 0.0015 |
| C21190 | R3, R4 | 0603 | Basic | 21,643,642 | 0.0026 |
| C23162 | R5, R6, R8 | 0603 | Basic | 22,449,325 | 0.0028 |
| C31900351 | U1 | QFN-88 | Extended | 112 | 15.7949 |
| C18221627 | U10 | QFN-28(4X4) | Extended | 5,472 | 3.2400 |
| C7519 | U11 | SOT-23-6L | Extended | 34,765 | 0.1767 |
| C117907 | U2 | TSOP-48-18.4mm | Extended | 108 | 3.3749 |
| C54935 | U3 | SOIC-28-300mil | Extended | 1,000 | 10.3945 |
| C352976 | U4, U5, U6 | TSSOP-20 | Extended | 4,375 | 0.5593 |
| C27643 | U7 | TSSOP-24 | Extended | 57,632 | 0.3479 |
| C5446 | U8 | SOT-23-3L | Basic | 472,796 | 0.1426 |
| C236672 | U9 | SOT-23-5 | Extended | 10,931 | 0.0620 |
| C7434936 | X1 | SMD2520-4P | Extended | 6,005 | 0.5788 |
| C367183 | Y1 | SMD3225-4P | Extended | 10,992 | 0.3363 |

Order estimate:

| Boards | Bare PCB (ENIG) [Q] | Parts [P] | **Total, Economic PCBA** | Total, Standard PCBA |
|---|---|---|---|---|
| 5 | $24.60 | $185.90 | **$257.37** ($51.47/board) | $283.63 ($56.73/board) |
| 10 | $30.60 | $335.30 | **$416.14** ($41.61/board) | $442.76 ($44.28/board) |
| 30 | $53.20 | $890.15 | **$1007.13** ($33.57/board) | $1035.13 ($34.50/board) |
| 100 | $73.50 | $2663.20 | **$2847.86** ($28.48/board) | $2880.70 ($28.81/board) |

- **Use Standard PCBA.** The USB-C receptacle has 4 through-hole shell legs, which need hand
  soldering, and the FPGA is a 0.4 mm-pitch QFN-88. The Economic rows are shown for comparison; JLC may
  route the order to Standard anyway. The THT fee is an estimate [E].
- **0.1 mm clearance:** the QFN-88 pads are 0.1 mm apart, so the board uses 0.1 mm clearance and
  0.1 mm neck-downs. JLC's 4-layer process allows 0.09 mm; check the price after uploading the gerbers,
  in case the quote page adds a fine-trace charge [E].
- The FPGA (C31900351, 112 in stock) and flash (C117907, 108 in stock) limit a single order to about 100 boards.
- The FPGA needs its bitstream after assembly: load it over USB with `openFPGALoader -c ch347_jtag`
  (see `programmer/README.md`).

## How to order

1. Bare PCB: upload `exports/jlcpcb/gerbers.zip` (r1.1) or `r2/board/exports/jlcpcb/gerbers.zip` (r2.1)
   at jlcpcb.com. Set **thickness 1.0 mm** and **ENIG** (or gold fingers with a 30° bevel); r2.1 is
   detected as 4 layers.
2. Assembly: turn on PCB Assembly, top side. Upload `bom.csv` and `cpl.csv` from the same folder. Pick
   Standard for r2.1.
3. Check the rotation preview: SOIC, PLCC, TSOP and QFN reels sometimes need ±90°/180°, and check pin 1.
   Leave J1 (edge fingers) and TP1–TP6 (test pads) unplaced; they are not in the BOM.

## Shipping (all [E] unless noted)

| Destination | Global Standard Direct (economy, DDP) | DHL Express |
|---|---|---|
| USA, bare PCBs 5-30 pcs | ~$12-13 incl. prepaid tariff (forum report, 2026-03-19: "$10 boards + ~$2 tax + ~$12 shipping") | ~$35-45 (forum report, 2026-03-06: "$5 of PCBs for $45" by DHL) |
| USA, PCBA or 100 pcs (~0.7-1 kg) | ~$18-30 [E] | ~$40-60 [E] |
| Thailand, bare PCBs | ~$6-12 [E] | ~$20-30 [E] |
| Thailand, PCBA or 100 pcs | ~$12-20 [E] | ~$30-45 [E] |

- For US orders, choose the DDP or "Global Standard Direct Line" option so the tariff is prepaid. Express (DAP) can bring a broker or duty bill on delivery.
- Thailand charges 7% VAT on low-value imports (since 2024), which may be collected at checkout or on delivery [E].

## Cartridge shell (separate line)

| Item | Price | Source / date |
|---|---|---|
| Generic DMG-style cart shell (AliExpress bulk, 10-50 pack) | ~$0.30-2.00 each [E] | gbstudiocentral.com cart-shell guide: "10 cents to 3 bucks"; date not shown |
| Quality shell (Retro Modding) | $3.99 each; 12-colour pack $44.99 | same guide |
| Gamebit 3.8 mm screw / driver | ~$0.10 per screw, ~$3 driver [E] | AliExpress listings |

r1.1 and r2.1 use the standard DMG board outline, so any DMG-style shell fits (`mech/fit.html`). r2.1 needs the printed USB-C shell from `mech/`, or a shell cut open over the connector.

## Sources
- JLCPCB quote engine (cart.jlcpcb.com) and parts API (jlcpcb.com), queried 2026-10-01.
- JLCPCB help: "PCB Assembly Cost" (2026-09-09); "In what cases will there be charged extra?" (2026-09-09, ENIG >30% area surcharge); "JLCPCB gold fingers" (2026-09-18).
- JLCPCB news: "Free OSP Surface Finish" (2026-07-30).
- JLC part page C632847 (assembly type, MSL3).
- allaboutcircuits.com thread "JLCPCB Global Standard Direct Line Shipping" (2026-03-06 to 2026-03-19).
- gbstudiocentral.com "GB Game Cartridge Shells".

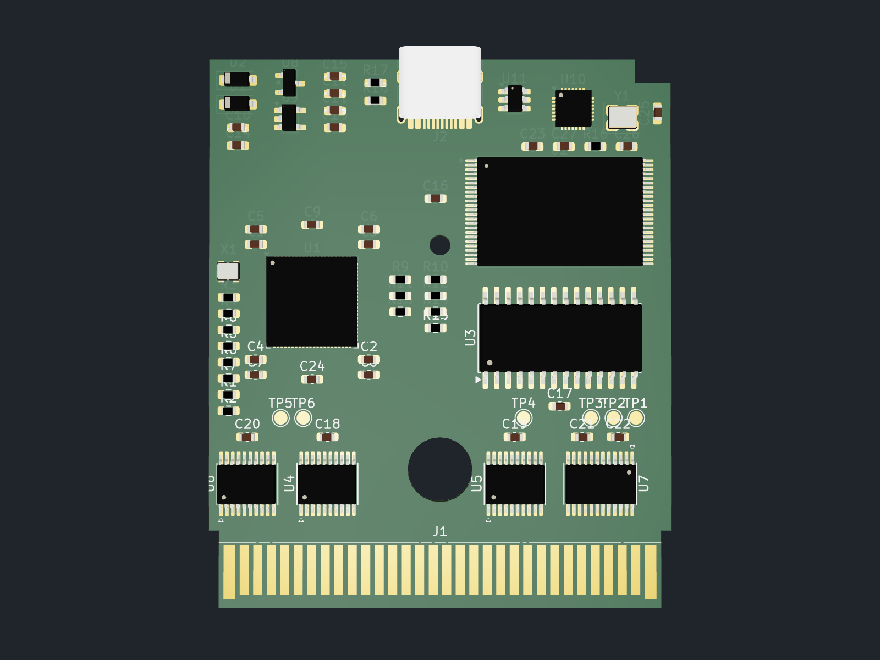
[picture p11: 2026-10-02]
r2/board/renders/3d-top.png

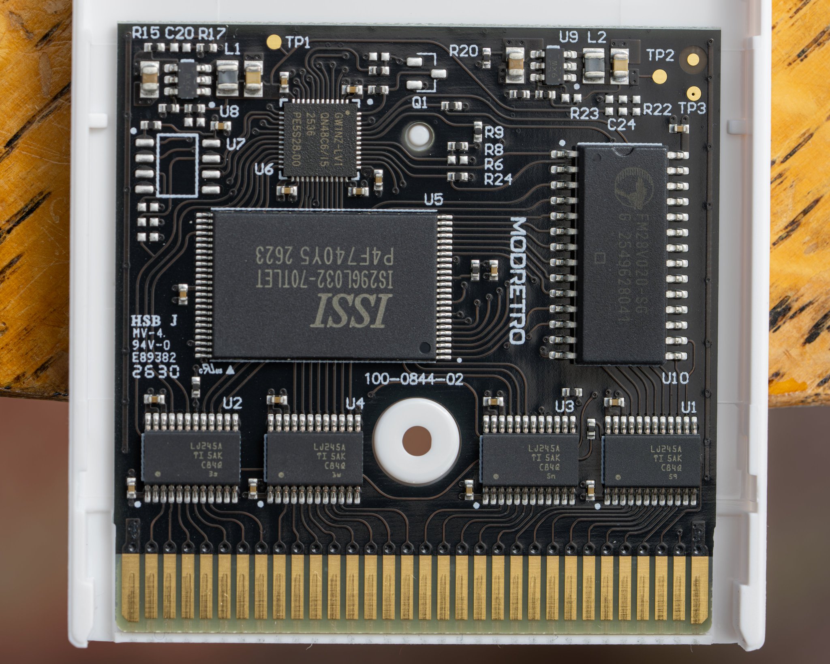
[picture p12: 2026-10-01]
sketches/modretro-demo-cart-reference.jpg

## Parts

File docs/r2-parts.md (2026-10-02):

# GB DEVCART r2: parts research (FPGA mapper, 4-layer, 56 x 50 mm)

Snapshot taken **2026-10-02**. Prices are USD unit prices from the JLCPCB/LCSC parts API (`selectSmtComponentList`) unless marked otherwise.
Tags: **[P]** parts API, queried 2026-10-02. **[Q]** live JLC quote engine (`cart.jlcpcb.com` `calculationGoodsCosts`), queried 2026-10-02.
**[D]** vendor datasheet (version and date given). **[E]** estimate or unverified, so check it before ordering.
"Ext" means a JLC Extended part. Under Economic PCBA each one costs a $3.07 loading fee per order.

## Recommended parts per role [P]

| Role | MPN | LCSC | Lib | Stock | $ @10 | $ @100 | KiCad footprint | Datasheet |
|---|---|---|---|---|---|---|---|---|
| FPGA | **GW1NZ-LV1QN48C6/I5** | **C5799569** | Ext | 912 | 5.59 | 4.44 | `Package_DFN_QFN:QFN-48-1EP_6x6mm_P0.4mm_EP4.4x4.4mm` [E] | cdn.gowinsemi.com.cn/DS841E.pdf, pinout cdn.gowinsemi.com.cn/UG842E.pdf |
| ROM 8 MB | **S29GL064N90TFI040** | **C117907** | Ext | 108 | 2.86 | 2.25 | `Package_SO:TSOP-I-48_18.4x12mm_P0.5mm` | lcsc.com/datasheet/lcsc_datasheet_2304140030_Infineon-Cypress-Semicon-S29GL064N90TFI040_C117907.pdf |
| Save RAM 32 KB | **FM28V020-SGTR** | **C54935** | Ext | 1,000 | 9.16 | 6.97 | `Package_SO:SOIC-28W_7.5x17.9mm_P1.27mm` (same as r1 U2) | lcsc.com/datasheet/lcsc_datasheet_1912111437_Infineon-Cypress-Semicon-FM28V020-SGTR_C54935.pdf |
| 5 V to 3.3 V, x3 | **74LVC245APW,118** (Nexperia) | **C6082** | Ext | 270,429 | 0.21 | 0.17 | `Package_SO:TSSOP-20_4.4x6.5mm_P0.65mm` | lcsc.com/datasheet/lcsc_datasheet_2407241045_Nexperia-74LVC245APW-118_C6082.pdf |
| Data bus, x1 | **SN74LVC8T245PWR** | **C27643** | Ext | 57,632 | 0.27 | 0.19 | `Package_SO:TSSOP-24_4.4x7.8mm_P0.65mm` | lcsc.com/datasheet/lcsc_datasheet_1810312312_Texas-Instruments-SN74LVC8T245PWR_C27643.pdf |
| 3.3 V LDO | **XC6206P332MR-G** | **C5446** | **Basic** | 474,338 | 0.14 | 0.12 | `Package_TO_SOT_SMD:SOT-23` | lcsc.com/datasheet/lcsc_datasheet_2304140030_Torex-Semicon-XC6206P332MR-G_C5446.pdf |
| 1.2 V LDO | **ME6211C12M5G-N** | **C236672** | Ext | 10,931 | 0.06 | 0.05 | `Package_TO_SOT_SMD:SOT-23-5` | lcsc.com/datasheet/lcsc_datasheet_2304140030_MICRONE-Nanjing-Micro-One-Elec-ME6211C12M5G-N_C236672.pdf |

## Alternates [P]

| Role | MPN | LCSC | Lib | Stock | $ @10 | $ @100 | Note |
|---|---|---|---|---|---|---|---|
| FPGA | ICE40UP5K-SG48I | C2678152 | Ext | 261 | 9.61 | 8.10 | QFN-48 7x7 (`QFN-48-1EP_7x7mm_P0.5mm_EP5.6x5.6mm` [E]). 1.2 V core. Needs an external SPI flash: W25Q32JVSSIQ **C179173** (17,363 stock, $1.30/$1.04, `Package_SO:SOIC-8_5.23x5.23mm_P1.27mm`). Best-supported open-source flow (IceStorm). |
| FPGA | ICE40HX1K-VQ100 | C1519043 | Ext | **35** | 11.63 | 8.94 | TQFP-100 is too large for a 56 x 50 mm board alongside a TSOP-48. Needs SPI flash. |
| FPGA | GW1N-LV1QN48C6/I5 | C5799563 | Ext | **0** | 24.38 | - | Pin-compatible sibling. Out of stock. LV1FN32 (C5453972) and LV1CS16 also show 0. |
| ROM 8 MB | S29GL064S70TFI040 | C914938 | Ext | 87 | 4.55 | 3.63 | Newer "S" die, 70 ns, same pinout. Drop-in. |
| ROM 8 MB | MX29LV640EBTI-70G | C30076 | Ext | **13** | 5.58 | 4.71 | TSOP-48 x8/x16 bottom boot. Low stock. |
| ROM 4 MB | S29GL032N90TFI040 | C117908 | Ext | 119 | 3.73 | 2.92 | Same family and pinout, half the size. Costs more than the 064 today. |
| ROM (no) | SST39VF6401B / 3201B (C36836, C46322) | | Ext | 62/96 | 6.06/6.18 | | **x16 only, no BYTE# pin.** Not suitable. |
| Save RAM | FM18W08-SGTR | C55945 | Ext | **45** | 9.58 | 9.58 | 2.7-5.5 V, same JEDEC 32Kx8 pinout and footprint. Works at 3.3 V but has less stock. |
| Save RAM (no) | FM28V020-TG | C2947417 | Ext | 10 | 24.94 | | TSOP-32, expensive. |
| Translator | SN74LVC4245APWR | C7859 | Ext (Preferred) | 122,578 | 0.39 | 0.28 | Classic octal 5 V/3.3 V transceiver with DIR. Alternative to the 8T245. |
| Translator | SN74LVC16T245DGGR | C148170 | Ext | 2,618 | 1.49 | 1.16 | 16-bit dual-supply, TSSOP-48. Two of them would cover all 29 GB lines in 2 parts but cost about 3x more. |
| 3.3 V LDO | ME6211C33M5G-N / AP2112K-3.3TRG1 | C82942 / C51118 | Ext | 165k / 38.8k | 0.06 / 0.17 | 0.05 / 0.14 | 500 / 600 mA, SOT-23-5 with EN pin. Use one if the 3.3 V rail needs more than 200 mA. |
| 1.2 V LDO | XC6206P122MR-G (Torex) / AP2112K-1.2TRG1 | C424699 / C460310 | Ext | 2,383 / 200 | 0.16 / 0.36 | 0.13 / 0.28 | SOT-23 / SOT-23-5. |

## Notes per role

**1. FPGA: GW1NZ-LV1 (GW1NZ-1) in QN48.** Specs are from [D] DS841 v2.8E (2026-04-03) and UG842 v1.6.8E (2026-03-09).
- 1,152 LUT4s, 864 FFs, 72 Kbit BSRAM, 1 PLL, 64 Kbit user flash, internal config flash (instant-on, no SPI chip). **QN48 has 41 user I/O, maximum.**
- Core VCC (LV part) is **1.2 V nominal**, range 1.07-1.26 V. VCCIO0/VCCIO1 range 1.14-3.6 V, so 3.3 V is fine. VCCX (auxiliary) range 1.71-3.6 V and must be at least VCCIO, so tie it to 3.3 V. The absolute maximum on any I/O is 3.75 V, so the pins are **not 5 V tolerant**.
- VCC ramp rate must be between 0.6 and 6 mV/us, i.e. the 1.2 V rail must take at least 200 us to come up. Check the LDO soft-start, or add an RC on EN or a larger output capacitor [E].
- QN48 power pins: VCC 12 and 37, VCCIO0 1, VCCIO1 25, VCCX 36, VSS 2 and 26 plus the EPAD (GND recommended).
- JTAG pins: **TCK 3, TMS 4, TDI 5, TDO 7**. Config pins: JTAGSEL_N 44, RECONFIG_N 48, DONE 46, READY 45, MODE0 43, MODE1 42 (MODE2 is internally grounded).
- JTAG pins become GPIO unless JTAGSEL_N is held low. Keep JTAG dedicated (pull JTAGSEL_N low, or leave the pins unused as GPIO) so the part cannot lock you out. That leaves about **35 usable I/O**.
- Open-source flow: the Apicula README (checked 2026-10-02) lists the *Sipeed Tang Nano 1K: GW1NZ-LV1QN48C6/I5* as a supported board, using yosys `synth_gowin`, nextpnr-himbaechel (gowin) and gowin_pack. openFPGALoader's FPGAs.yml lists GW1NZ-1 with "Memory: OK, Flash: IF", meaning SRAM load and internal-flash programming both work. This is the same chip as the Tang Nano 1K, which makes it a good dev board for bring-up.
- I/O budget, assuming the memories take buffered GB A0-A13 directly and the FPGA only decodes.
  - Inputs, 17: A12-A15, D0-D7, /RD, /WR, /CS, CLK, /RST.
  - Outputs, 16: ROM A13-A21 (9 bank bits), ROM /CE, ROM /WE gate, RAM /CE, RAM A13-A14, xcvr DIR, xcvr /OE.
  - Total: 33, plus 4 JTAG, is **37 of 41**. That leaves room for an LED or 2 I2C pins for an RTC, and nothing more. Full 16-bit address decode in the FPGA does **not** fit.

**2. ROM: S29GL064N, model 04.** Model 04 is the TSOP-48, x8/x16, bottom-boot version. Models 06/07 are x16-only [E: from memory of the S29GL-N ordering table, so check this in the datasheet before ordering].
- 2.7-3.6 V supply, 90 ns access, AMD/JEDEC command set. Tie **BYTE# low** for x8 mode. DQ15 then becomes A-1 (the byte LSB): wire GB A0 to A-1, GB A1-A13 to A0-A12, and the FPGA bank bits to A13-A21.
- In byte mode, unlock and program use **0xAAA/0xAA, 0x555/0x55, 0xAAA/0xA0**. Word mode uses 0x555/0x2AA. Autoselect and erase follow the same pattern (0x80, 0x10/0x30).
- WP#/ACC needs a pull-up and RESET# a pull-up or an FPGA pin.
- With the shifters' few ns of delay, 90 ns fits easily in the GB access window, including CGB double speed.

**3. Save RAM: FM28V020-SGTR.** This is the pick: 1,000 in stock, cheaper than the FM18W08-SGTR (45 in stock), and specified for 2.0-3.6 V. It sits on the 3.3 V side, so its 3 V-only rating does not matter.
- Same JEDEC 32Kx8 SOIC-28 (300 mil) pinout as r1's FM18W08, so the r1 footprint carries over.
- F-RAM needs no battery. /CE must toggle on every access (the RAM is address-latched on the /CE falling edge). Drive /CE from the FPGA, qualified by the GB /CS (A000-BFFF) and RAM enable, so the r1 CE-gating logic moves into the FPGA.

**4. Level shifting.** The GB cart edge is 5 V. Every GW1NZ pin has an absolute maximum of 3.75 V.
- (a) Address and control, 5 V to 3.3 V: **3x 74LVC245APW** with VCC = 3.3 V, DIR tied to B to A, /OE to GND. That gives 24 channels for A0-A15, /RD, /WR, /CS, CLK, /RST, with 3 spare. The datasheet allows inputs up to 5.5 V at VCC = 3.3 V.
- (b) Data bus: **SN74LVC8T245** with VCCA = 3.3 V and VCCB = 5 V (the cart's VCC). The FPGA drives DIR and /OE: B to A by default, A to B only while /RD is low and the cart is selected.
- Driving the data bus with a 74LVC245 at 3.3 V, so VOH is about 3.0-3.3 V, does work electrically: its I/O tolerates 5 V while it is receiving. But Nintendo publishes no V_IH for the DMG or CGB CPU. Forum reports put the input threshold at TTL-like levels (about 2.0-2.4 V), which would make 3.3 V work but with a thin margin [E].
- Against a CMOS 0.7 x VCC threshold (3.5 V), 3.3 V is out of spec. The 8T245 costs $0.06 more than a 245, so do not take the risk.
- ModRetro Chromatic: I found **no public schematic or teardown data (as of 2026-10-02)** on its cart-port voltages or buffers. Assume 5 V cart signalling like DMG/CGB. The dual-supply 8T245 is also safe if the port turns out to run at 3.3 V, because both sides accept 1.65-5.5 V.

**5. Regulators.**
- 3.3 V: **XC6206P332MR-G** (Basic, so no loading fee). 200 mA maximum, about 250 mV dropout at 100 mA. Estimated load is 40-80 mA (flash read about 30 mA, program about 50 mA, FPGA plus F-RAM plus logic about 20 mA) [E].
- 1.2 V: **ME6211C12M5G-N**, fed from the 3.3 V rail. That costs less dissipation than feeding it from 5 V, and EN is available for sequencing and ramp control.
- Power-up order: VCCX/VCCIO (3.3 V) first, then 1.2 V, which suits the GW1NZ.

**6. RTC (MBC3), optional.** It is feasible, but the clock must keep running while the cart is unpowered, so the FPGA cannot do it.
- Parts: **PCF8563T/5** (C7440, Ext *Preferred*, 21,338 stock, $0.51/$0.38, `Package_SO:SOIC-8_3.9x4.9mm_P1.27mm`), a 32.768 kHz crystal **Q13FC13500004** (C32346, **Basic**, $0.17, `Crystal:Crystal_SMD_3215-2Pin_3.2x1.5mm`) and a CR1220 holder (e.g. C70381, $0.24).
- That adds about **$0.95 per board plus $3.07 loading per order**. The FPGA emulates MBC3 latch registers over I2C, using 2 of the remaining spare pins.

## PCB: 4-layer, 56 x 50 mm, 1.0 mm, ENIG 1u", green, FR-4 Tg140, 1 oz outer / 0.5 oz inner [Q] (2026-10-02)

| Finish | 5 pcs | 10 pcs | 30 pcs | 100 pcs |
|---|---|---|---|---|
| **ENIG 4L** | **$24.60** | **$30.60** | $52.00 | $70.20 |
| HASL (leaded) 4L | $8.00 | $14.00 | $34.00 | $48.90 |
| (r1 reference) ENIG 2L, same query | $18.60 | $21.60 | - | - |

- The ENIG upcharge is the same flat $16.60 per order as on 2L. 4L adds $6.00 at 5 pcs and $9.00 at 10 pcs over 2L.
- r1 noted that JLC wants gold-finger boards at least 50 mm per side. **50 mm meets that.**
- Check in the cart that Economic PCBA accepts 4-layer boards and 0.4 mm-pitch QFN; otherwise use Standard PCBA [E].

## BOM per board at 10 boards (parts only, list price @10) [P]

| Item | $ |
|---|---|
| FPGA 5.59 + ROM 2.86 + F-RAM 9.16 | 17.61 |
| 3x 74LVC245 (0.64) + 8T245 (0.27) + two LDOs (0.20) | 1.11 |
| Passives: ~16x 100 nF, ~4x 1-10 uF, ~8 resistors (Basic) [E] | ~0.60 |
| **r2 parts total** | **~$19.3** (RTC option adds ~$0.95) |
| r1 parts total (docs/jlcpcb-pricing.md, 2026-10-01) | $16.32 |

- **Assembled at 10 pcs, Economic [E]:**
  - PCB: $3.06 per board.
  - Parts: $19.3 per board.
  - Fees: $8.18 setup + $1.53 stencil + 6 Extended x $3.07 = $28.12 per order, about $2.81 per board.
  - Joints: about 280 at $0.0016, about $0.48 per board.
  - Total: **about $25.7 per board, about $257 per order**, versus about $21.46 per board for r1.
- F-RAM is still the largest line, about 47% of r2 parts. At 100 boards r2 parts fall to about $15.0 (FPGA $4.44, F-RAM $6.97) [P].
- Stock today (2026-10-02) covers 100 boards for every recommended line.

## Sources (all accessed 2026-10-02)
- JLCPCB parts API `jlcpcb.com/api/overseas-pcb-order/v1/shoppingCart/smtGood/selectSmtComponentList`. JLC quote engine `cart.jlcpcb.com/api/overseas-shop-cart/v1/shoppingCart/calculationGoodsCosts`.
- Gowin DS841 *GW1NZ series Datasheet* v2.8E (2026-04-03). Gowin UG842 *GW1NZ-1 Pinout* v1.6.8E (2026-03-09). Both from cdn.gowinsemi.com.cn.
- github.com/YosysHQ/apicula readme.md. github.com/trabucayre/openFPGALoader doc/FPGAs.yml.
- KiCad footprint names checked against the local standard library at /home/user/tools/footprints.

## USB / FPGA v2 (added 2026-10-02 after the "USB connector to program it" change)

The FPGA now drives ROM and F-RAM directly, and a USB-C bridge provides JTAG and UART. Pin tables are in `docs/r2-pinouts.json`.

| Role | Pick | LCSC | Stock | $ @10 / @100 | KiCad footprint |
|---|---|---|---|---|---|
| FPGA | **GW1N-LV4QN88C6/I5** | C31900351 | 112 | 14.96 / 12.26 | `Package_DFN_QFN:ArtInChip_QFN-88-1EP_10x10mm_P0.4mm_EP6.74x6.74mm` (EP geometry unverified) |
| FPGA alt | GW1NR-LV9QN88PC6/I5 (Tang Nano 9K chip) | C5799578 | 173 | 22.06 / 18.07 | same |
| USB bridge | **CH347F** (QFN-28) | C18221627 | 5,472 | 2.78 / 2.22 | `Package_DFN_QFN:QFN-28-1EP_4x4mm_P0.4mm_EP2.4x2.4mm` |
| USB bridge alt | CH347T (TSSOP-20, mode-3 straps) | C5122332 | 857 | 2.89 / 2.21 | `Package_SO:TSSOP-20_4.4x6.5mm_P0.65mm` |
| 8 MHz crystal | XXDCELNANF-8MHZ (TAITIEN) | C367183 | 10,992 | 0.34 / 0.27 | `Crystal:Crystal_SMD_3225-4Pin_3.2x2.5mm` |
| USB-C | HRO TYPE-C-31-M-12 | C165948 | 448,022 | 0.19 / 0.15 | `Connector_USB:USB_C_Receptacle_HRO_TYPE-C-31-M-12` |
| ESD | USBLC6-2SC6 (ST); C2687116 (UMW) $0.05 | C7519 | 36,352 | 0.18 / 0.14 | `Package_TO_SOT_SMD:SOT-23-6` |
| 5 V OR diodes (x2) | B5819W SL (**Basic**) | C8598 | 510,793 | 0.03 | `Diode_SMD:D_SOD-123` |
| CC pull-downs (x2) | 5.1k 0603 (**Basic**) | C23186 | 25M | 0.002 | `Resistor_SMD:R_0603_1608Metric` |
| Bus-hold buffer (x3) | SN74LVCH245APWR (TI) | C352976 | 4,515 | 0.56 / 0.43 | `Package_SO:TSSOP-20_4.4x6.5mm_P0.65mm` |

**FPGA.** The GW1N-LV9 is out of stock in every package at LCSC on 2026-10-02 (QN88, LQ100 and QN48 all show 0). That leaves two QN88 (10 x 10 mm) parts in stock.
- **GW1N-LV4 QN88 is the pick.** Sources: UG105 v1.8.5E and apicula 0.32.
  - It has 71 user I/O (bank 0: 20, bank 1: 15, bank 2: 23, bank 3: 13). All four VCCIO banks can be 3.3 V.
  - Supplies: VCC 1.2 V (1.14-1.26 V), VCCX 3.3 V (2.375-3.6 V). It has internal flash, so it auto-boots with MODE[2:0]=000.
  - About 64 I/O are left free once JTAG, RECONFIG_N, DONE and MODE0/1 are taken.
- **GW1NR-LV9 QN88P is the fallback.** It is the best-tested apicula part, but UG803 v1.6.5E requires **VCCIO3 = 1.8 V** because that bank feeds the embedded PSRAM. That bank holds 23 I/O including JTAG.
  - So it gives only 48 I/O at 3.3 V and needs an extra 1.8 V LDO.
- **I/O budget is tight on either part:** about 64 usable against about 71 needed.
  - The 71 is: 29 GB-side lines + 23 ROM address (A-1..A21) + 8 data + ROM CE/OE/WE/RESET/RY + RAM CE + transceiver DIR/OE + 2 UART.
  - To fit, share the address, data and OE/WE lines between ROM and F-RAM. Drop RY/BY# (poll the DQ6 toggle bit instead) and drive RESET# from an RC. Consider not giving GB A0-A13 their own FPGA pins.
- **Open-source flow (checked 2026-10-02).**
  - The apicula chipdb contains GW1N-4 QFN88 and GW1NR-9C QFN88P pinouts.
  - openFPGALoader FPGAs.yml lists GW1N-4 and GW1NR-9/9C as "Memory OK, Flash IF".
  - **Unverified:** which GW1N-4 die revision (B or D) LCSC ships, and whether apicula's GW1N-4 database matches it. Apicula's only listed GW1N-4 board is the UV4 LQ144. Confirm with a first prototype or with the Gowin IDE before committing.

**USB bridge.**
- openFPGALoader cable `ch347_jtag` accepts both CH347T (PID 0x55DD) and CH347F (PID 0x55DE), per `src/ch347jtag.cpp`, checked 2026-10-02.
- I picked the **CH347F**:
  - No mode straps; UART, JTAG, SPI and I2C are all available at once.
  - It has a VIO pin (1.8-3.3 V), which also covers the 1.8 V JTAG bank if the GW1NR-9 is used.
  - 6x the stock of the CH347T.
- It needs **VCC = 3.3 V** (absolute max 4.0 V) and an **8 MHz** crystal with about 22 pF to GND on each side. UD+/UD- connect straight to the connector with no series resistors.
- Pins: JTAG on TCK 23, TMS 26, TDI 25, TDO 24; UART on TXD0 19, RXD0 22.
- The FT2232HL (C27882, $10.33) and a CH552 running ch552_jtag firmware also work with openFPGALoader. The FT2232HL costs more. The CH552 needs firmware flashed before use.

**Power.**
- VBUS and cart-edge 5 V each go through a B5819W into the 5 V rail. This stops USB from back-powering the console.
- Feed the 8T245's VCCB from the **cart-edge** 5 V, before the diode. When no console is present, its "either VCC = 0 means Hi-Z" isolation then takes effect.
- The 3.3 V load grows with the GW1N-4 and CH347F. If the budget goes over about 150 mA, use ME6211C33M5G-N (C82942, 500 mA) instead of the XC6206.

**Floating GB-side inputs (no console present).**
- **SN74LVCH245APWR** is a pin-for-pin drop-in for the 74LVC245A. Bus-hold is always on; TI says not to add pull resistors with it.
- Nexperia's 74LVCH245APW (C426764) has only 4 in stock.
- Alternative at no extra cost: keep the 74LVC245A, enable the FPGA's internal weak pull-ups on those inputs, and gate the GB logic on a "console present" input (the cart-edge 5 V through a divider).

**BOM delta at 10 boards [P/E].**
- FPGA: +$9.37 over the GW1NZ-LV1.
- USB block: CH347F, crystal, USB-C, ESD, 2 diodes and passives, about +$3.6.
- LVCH245 instead of LVC245: about +$1.05 for three.
- r2 parts come to **about $33 per board** (versus about $19.3 for the GW1NZ plan).
- Extended unique parts rise to about 10, so Economic loading fees are about $30.7 per order.

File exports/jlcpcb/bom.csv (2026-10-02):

Comment | Designator | Footprint | LCSC Part #
100nF CC0603KRX7R9BB104 | C1,C2,C3,C4,C5,C6 | C_0603_1608Metric | C14663
10uF CL31A106KBHNNNE | C7 | C_1206_3216Metric | C13585
10k 0603WAF1002T5E | R1 | R_0603_1608Metric | C25804
2.2k 0603WAF2201T5E | R2,R3,R4,R5,R6 | R_0603_1608Metric | C4190
SST39SF040 SST39SF040-55-4I-NHE-T | U1 | PLCC-32_11.4x14.0mm_P1.27mm | C632847
FM18W08 FM18W08-SGTR | U2 | SOIC-28W_7.5x17.9mm_P1.27mm | C55945
74HC574 SN74HC574DWR | U3 | SOIC-20W_7.5x12.8mm_P1.27mm | C10097
74HC32 SN74HC32DR | U4,U5 | SOIC-14_3.9x8.7mm_P1.27mm | C6838
74HC00 SN74HC00DR | U6 | SOIC-14_3.9x8.7mm_P1.27mm | C10090

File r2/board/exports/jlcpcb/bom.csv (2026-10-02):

Comment | Designator | Footprint | LCSC Part #
10uF | C10,C11,C15 | C_0603_1608Metric | C19702
1uF | C12,C13,C14 | C_0603_1608Metric | C15849
100nF | C1,C2,C3,C4,C5,C6,C7,C8,C9,C16,C17,C18,C19,C20,C21,C22,C23,C24,C27 | C_0603_1608Metric | C14663
22pF | C25,C26 | C_0603_1608Metric | C1653
B5819W B5819W SL | D1,D2 | D_SOD-123 | C8598
USB-C TYPE-C-31-M-12 | J2 | USB_C_Receptacle_HRO_TYPE-C-31-M-12 | C165948
10k | R1,R2,R7,R9,R10,R11,R12,R13,R14,R15,R16 | R_0603_1608Metric | C25804
5.1k | R17,R18 | R_0603_1608Metric | C23186
1k | R3,R4 | R_0603_1608Metric | C21190
4.7k | R5,R6,R8 | R_0603_1608Metric | C23162
GW1N-LV4QN88 GW1N-LV4QN88C6/I5 | U1 | ArtInChip_QFN-88-1EP_10x10mm_P0.4mm_EP6.74x6.74mm | C31900351
CH347F CH347F | U10 | QFN-28-1EP_4x4mm_P0.4mm_EP2.4x2.4mm | C18221627
USBLC6-2SC6 USBLC6-2SC6 | U11 | SOT-23-6 | C7519
S29GL064N S29GL064N90TFI040 | U2 | TSOP-I-48_18.4x12mm_P0.5mm | C117907
FM28V020 FM28V020-SGTR | U3 | SOIC-28W_7.5x17.9mm_P1.27mm | C54935
74LVCH245 SN74LVCH245APWR | U4,U5,U6 | TSSOP-20_4.4x6.5mm_P0.65mm | C352976
SN74LVC8T245 SN74LVC8T245PWR | U7 | TSSOP-24_4.4x7.8mm_P0.65mm | C27643
XC6206P332 XC6206P332MR-G | U8 | SOT-23 | C5446
ME6211C12 ME6211C12M5G-N | U9 | SOT-23-5 | C236672
48MHz OT3EL89CJI-111YLC-48M | X1 | Oscillator_SMD_Abracon_ASDMB-4Pin_2.5x2.0mm | C7434936
8MHz XXDCELNANF-8MHZ | Y1 | Crystal_SMD_3225-4Pin_3.2x2.5mm | C367183

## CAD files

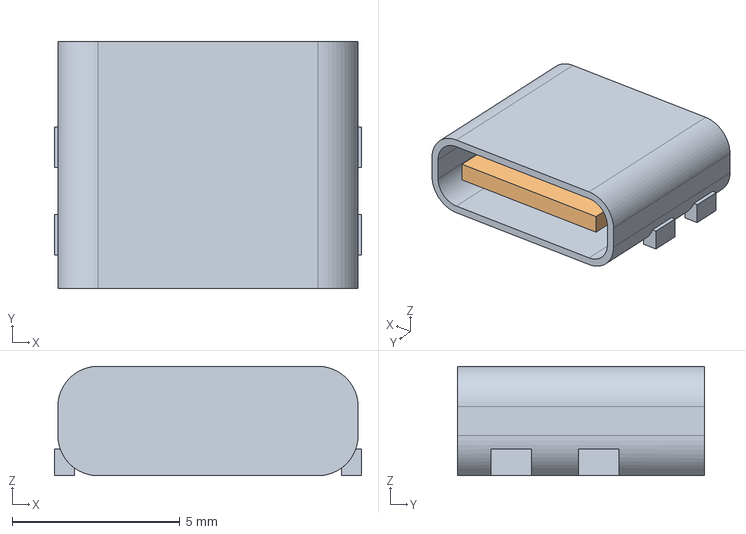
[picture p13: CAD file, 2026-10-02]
3dmodels/USB_C_Receptacle_HRO_TYPE-C-31-M-12.step
9.14 x 7.35 x 3.26 mm

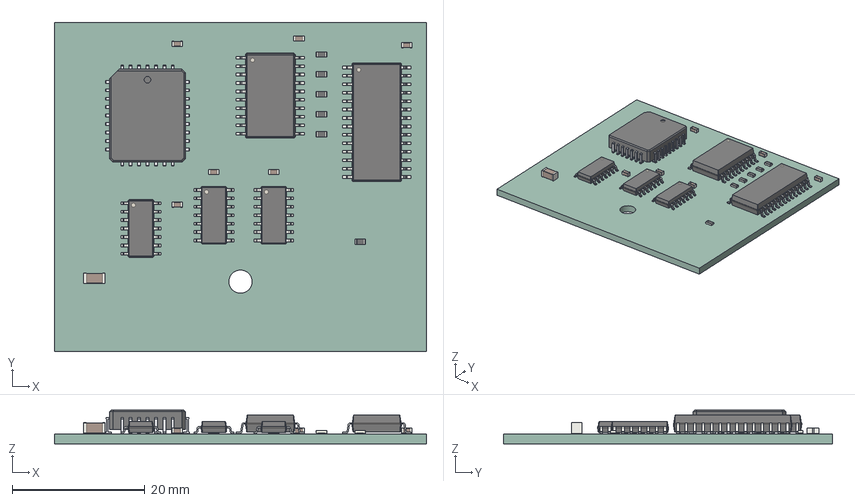
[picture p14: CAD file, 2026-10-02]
exports/board.step
56.0 x 49.5 x 5.09 mm
SOIC-14_3.9x8.7mm_P1.27mm x 3
R_0603_1608Metric x 6
SOIC-20W_7.5x12.8mm_P1.27mm
leads
C_0603_1608Metric x 6
SOIC-28W_7.5x17.9mm_P1.27mm
C_1206_3216Metric
board_PCB

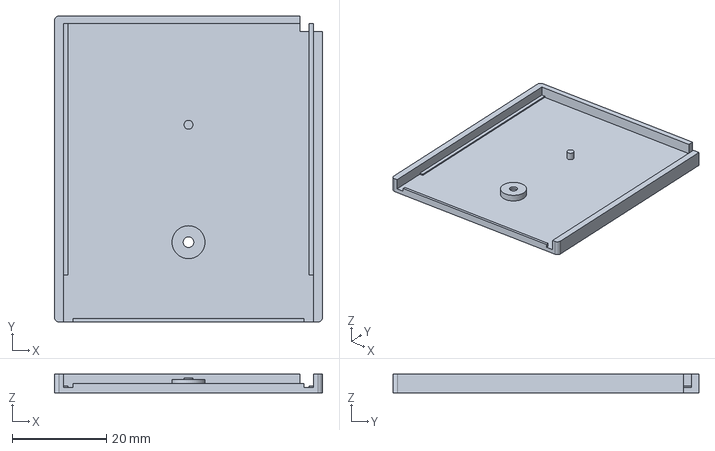
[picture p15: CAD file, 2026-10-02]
mech/out/shell_back.step
57.0 x 65.0 x 4.00 mm

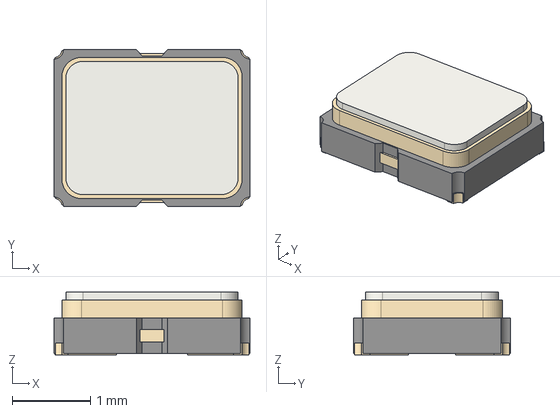
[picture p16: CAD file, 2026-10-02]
3dmodels/Oscillator_SMD_Abracon_ASDMB-4Pin_2.5x2.0mm.step
2.50 x 2.00 x 0.8 mm

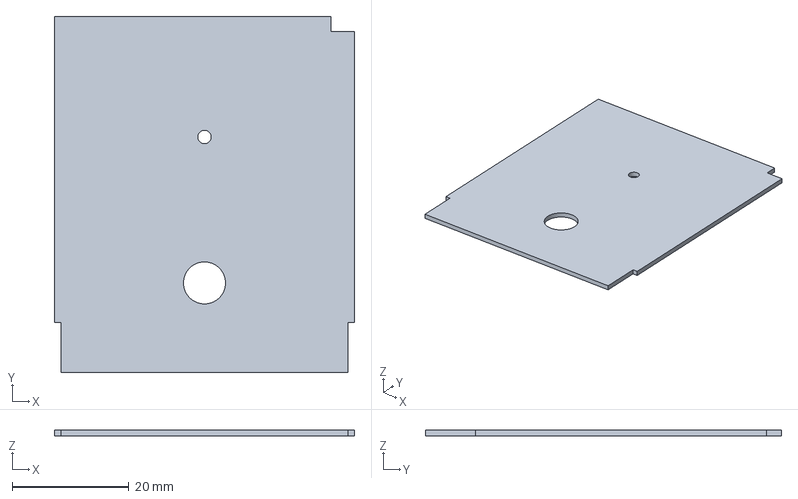
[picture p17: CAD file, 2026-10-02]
mech/out/pcb_std_outline.step
51.4 x 61.0 x 1.00 mm

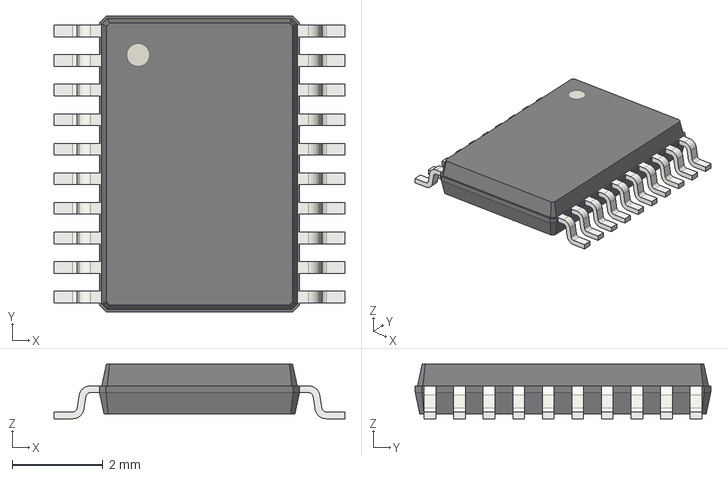
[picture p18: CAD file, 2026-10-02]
3dmodels/TSSOP-20_4.4x6.5mm_P0.65mm.step
6.40 x 6.50 x 1.20 mm

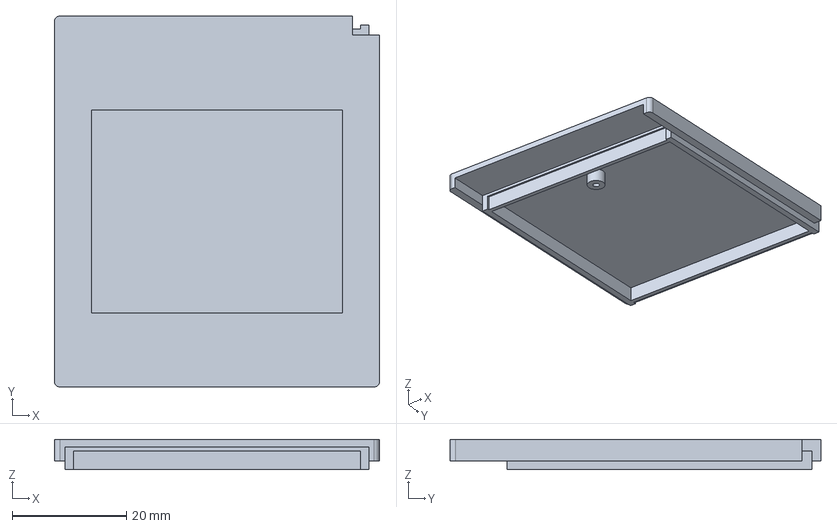
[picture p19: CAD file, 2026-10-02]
mech/out/shell_front_std.step
57.0 x 65.0 x 5.30 mm

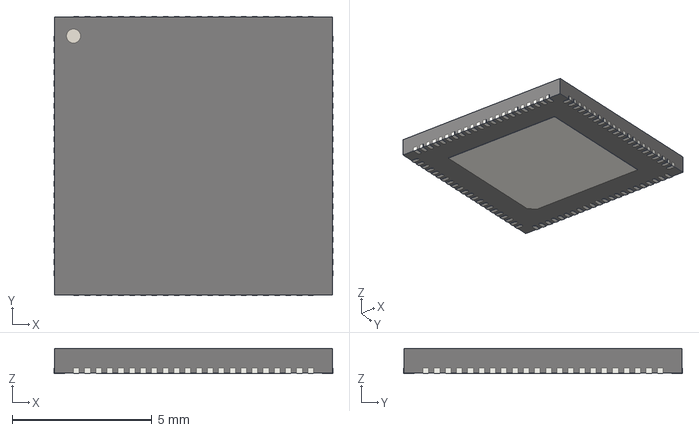
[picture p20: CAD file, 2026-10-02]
3dmodels/ArtInChip_QFN-88-1EP_10x10mm_P0.4mm_EP6.74x6.74mm.step
10.0 x 10.0 x 0.9 mm

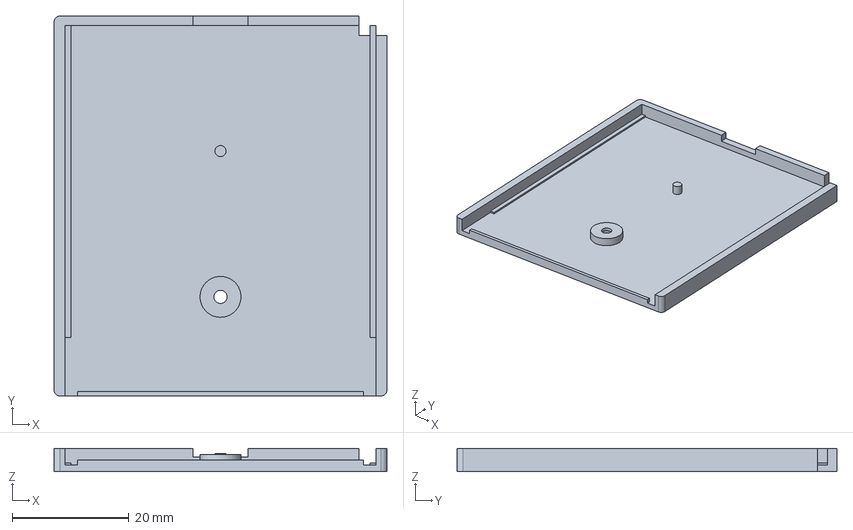
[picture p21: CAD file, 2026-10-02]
mech/out/shell_back_usb.step
57.0 x 65.0 x 4.00 mm

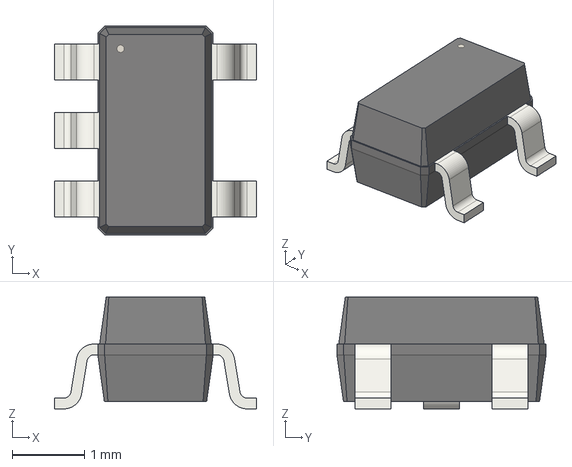
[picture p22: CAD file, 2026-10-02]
3dmodels/SOT-23-5.step
2.80 x 2.90 x 1.55 mm

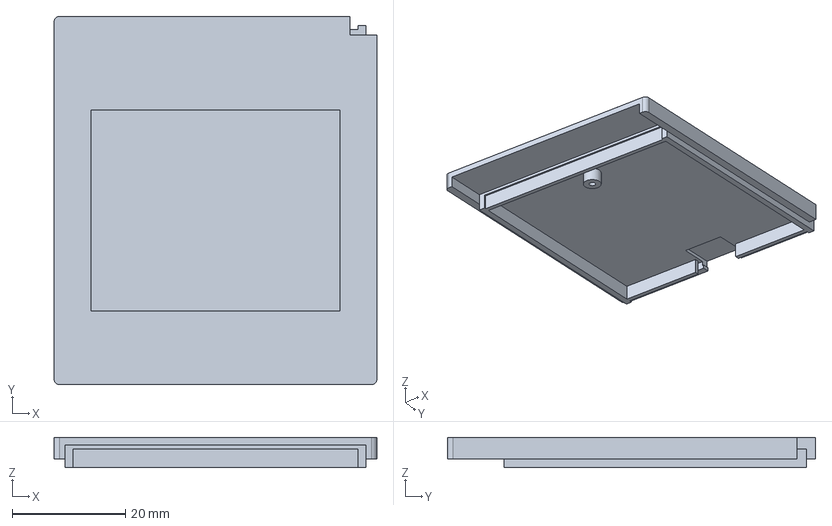
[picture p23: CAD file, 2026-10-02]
mech/out/shell_front_usb.step
57.0 x 65.0 x 5.30 mm

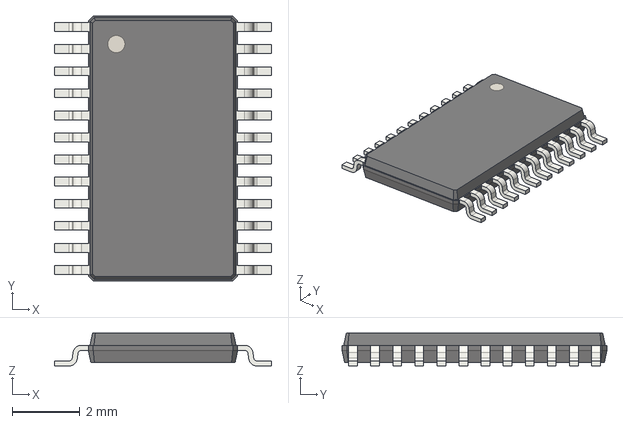
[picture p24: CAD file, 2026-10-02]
3dmodels/TSSOP-24_4.4x7.8mm_P0.65mm.step
6.40 x 7.80 x 0.97 mm

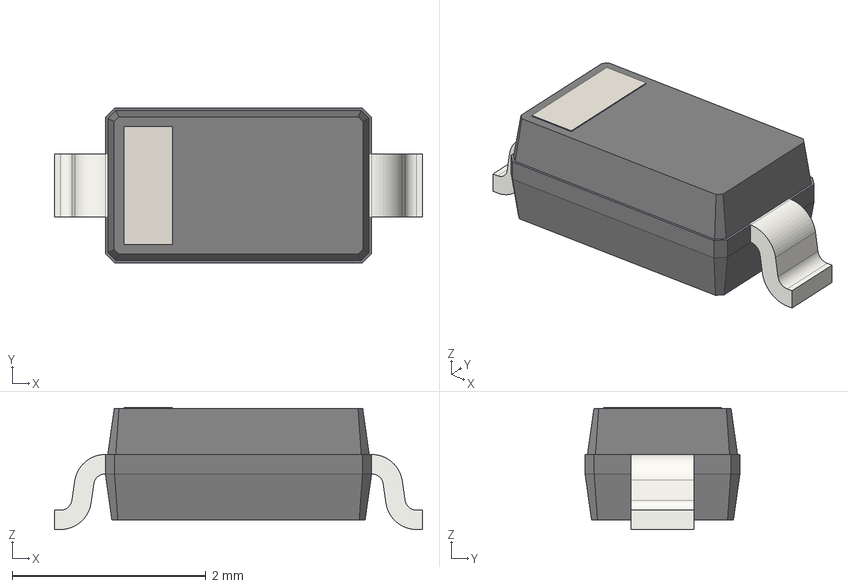
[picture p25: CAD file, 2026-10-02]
3dmodels/D_SOD-123.step
3.80 x 1.60 x 1.26 mm

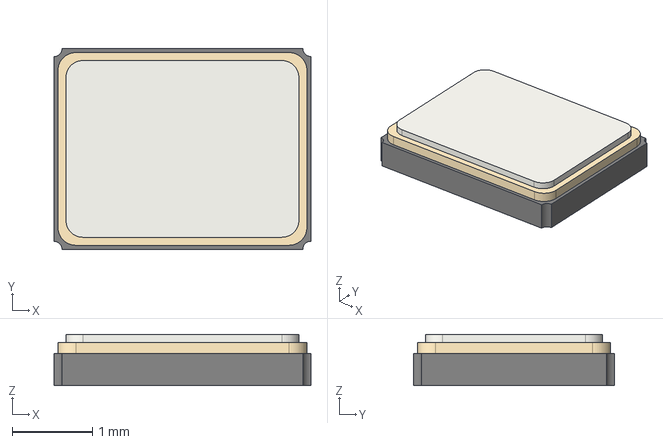
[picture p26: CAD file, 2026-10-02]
3dmodels/Crystal_SMD_3225-4Pin_3.2x2.5mm.step
3.20 x 2.50 x 0.64 mm

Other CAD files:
3dmodels/SOT-23-6.step
3dmodels/TSOP-I-48_18.4x12mm_P0.5mm.step
3dmodels/SOT-23.step
3dmodels/QFN-28-1EP_4x4mm_P0.4mm_EP2.4x2.4mm.step
3dmodels/C_0603_1608Metric.step
3dmodels/C_1206_3216Metric.step
3dmodels/PLCC-32_11.4x14.0mm_P1.27mm.step
3dmodels/R_0603_1608Metric.step
3dmodels/SOIC-14_3.9x8.7mm_P1.27mm.step
3dmodels/SOIC-20W_7.5x12.8mm_P1.27mm.step
3dmodels/SOIC-28W_7.5x17.9mm_P1.27mm.step
mech/out/pcb_std_outline.stl
mech/out/shell_back.stl
mech/out/shell_back_usb.stl
mech/out/shell_front_std.stl
mech/out/shell_front_usb.stl

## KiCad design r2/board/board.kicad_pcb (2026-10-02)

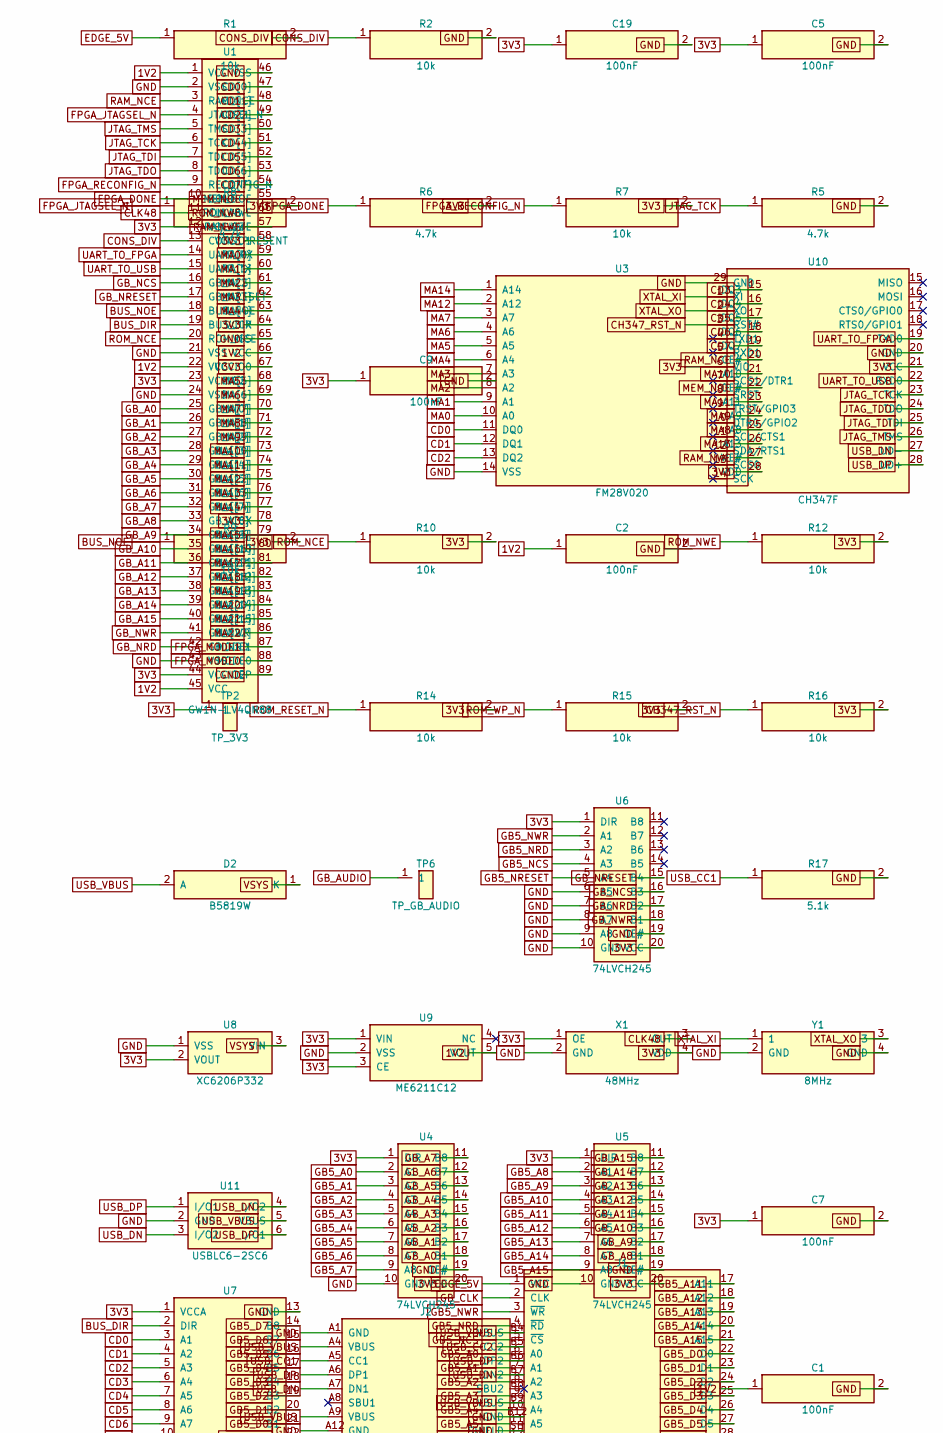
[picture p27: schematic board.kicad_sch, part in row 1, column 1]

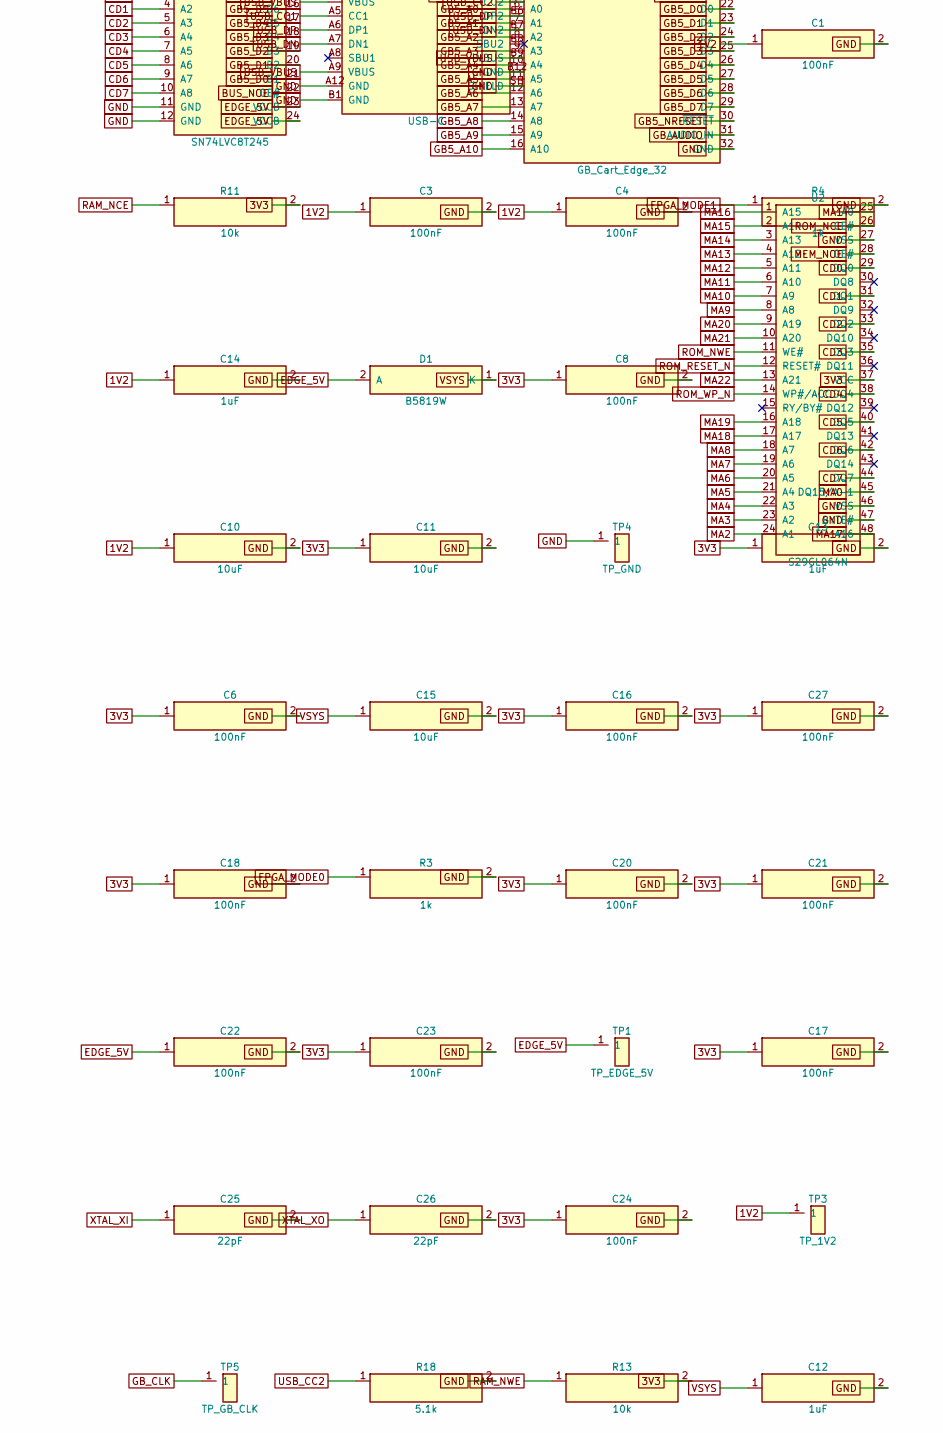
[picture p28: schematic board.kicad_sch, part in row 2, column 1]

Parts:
C1, C2, C3, C4, C5, C6, C7, C8, C9, C16, C17, C18, C19, C20, C21, C22, C23, C24, C27: 100nF; C_0603_1608Metric; LCSC C14663
C10, C11, C15: 10uF; C_0603_1608Metric; LCSC C19702
C12, C13, C14: 1uF; C_0603_1608Metric; LCSC C15849
C25, C26: 22pF; C_0603_1608Metric; LCSC C1653
D1, D2: B5819W; D_SOD-123; MPN B5819W SL; LCSC C8598
J1: GB_Cart_Edge_32; GB_Cart_Edge_32_DMG
J2: USB-C; USB_C_Receptacle_HRO_TYPE-C-31-M-12; MPN TYPE-C-31-M-12; LCSC C165948
R1, R2, R7, R9, R10, R11, R12, R13, R14, R15, R16: 10k; R_0603_1608Metric; LCSC C25804
R3, R4: 1k; R_0603_1608Metric; LCSC C21190
R5, R6, R8: 4.7k; R_0603_1608Metric; LCSC C23162
R17, R18: 5.1k; R_0603_1608Metric; LCSC C23186
TP1: TP_EDGE_5V; TestPoint_Pad_D1.5mm
TP2: TP_3V3; TestPoint_Pad_D1.5mm
TP3: TP_1V2; TestPoint_Pad_D1.5mm
TP4: TP_GND; TestPoint_Pad_D1.5mm
TP5: TP_GB_CLK; TestPoint_Pad_D1.5mm
TP6: TP_GB_AUDIO; TestPoint_Pad_D1.5mm
U1: GW1N-LV4QN88; ArtInChip_QFN-88-1EP_10x10mm_P0.4mm_EP6.74x6.74mm; MPN GW1N-LV4QN88C6/I5; LCSC C31900351
U2: S29GL064N; TSOP-I-48_18.4x12mm_P0.5mm; MPN S29GL064N90TFI040; LCSC C117907
U3: FM28V020; SOIC-28W_7.5x17.9mm_P1.27mm; MPN FM28V020-SGTR; LCSC C54935
U4, U5, U6: 74LVCH245; TSSOP-20_4.4x6.5mm_P0.65mm; MPN SN74LVCH245APWR; LCSC C352976
U7: SN74LVC8T245; TSSOP-24_4.4x7.8mm_P0.65mm; MPN SN74LVC8T245PWR; LCSC C27643
U8: XC6206P332; SOT-23; MPN XC6206P332MR-G; LCSC C5446
U9: ME6211C12; SOT-23-5; MPN ME6211C12M5G-N; LCSC C236672
U10: CH347F; QFN-28-1EP_4x4mm_P0.4mm_EP2.4x2.4mm; MPN CH347F; LCSC C18221627
U11: USBLC6-2SC6; SOT-23-6; MPN USBLC6-2SC6; LCSC C7519
X1: 48MHz; Oscillator_SMD_Abracon_ASDMB-4Pin_2.5x2.0mm; MPN OT3EL89CJI-111YLC-48M; LCSC C7434936
Y1: 8MHz; Crystal_SMD_3225-4Pin_3.2x2.5mm; MPN XXDCELNANF-8MHZ; LCSC C367183

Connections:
1V2: C1.1, C2.1, C3.1, C4.1, C10.1, C14.1, TP3.1 (1_1), U1.1 (VCC), U1.22 (VCC), U1.45 (VCC), U1.66 (VCC), U9.5 (VOUT)
3V3: C5.1, C6.1, C7.1, C8.1, C9.1, C11.1, C13.1, C16.1, C17.1, C18.1, C19.1, C20.1, C21.1, C23.1, C24.1, C27.1, R6.2, R7.2, R8.2, R9.2, R10.2, R11.2, R12.2, R13.2, R14.2, R15.2, R16.2, TP2.1 (1_1), U1.12 (VCCIO3), U1.23 (VCCIO2), U1.44 (VCCIO2), U1.58 (VCCIO1), U1.64 (VCCX), U1.67 (VCCIO0), U1.78 (VCCX), U2.37 (VCC), U3.28 (VDD), U4.1 (DIR), U4.20 (VCC), U5.1 (DIR), U5.20 (VCC), U6.1 (DIR), U6.20 (VCC), U7.1 (VCCA), U8.2 (VOUT), U9.1 (VIN), U9.3 (CE), U10.6 (VIO), U10.21 (VCC), X1.1 (OE), X1.4 (VDD)
BUS_DIR: U1.19 (BUS_DIR), U7.2 (DIR)
BUS_NOE: R9.1, U1.18 (BUS_NOE), U7.22 (OE#)
CD0: U1.47 (CD[0]), U2.29 (DQ0), U3.11 (DQ0), U7.3 (A1)
CD1: U1.48 (CD[1]), U2.31 (DQ1), U3.12 (DQ1), U7.4 (A2)
CD2: U1.49 (CD[2]), U2.33 (DQ2), U3.13 (DQ2), U7.5 (A3)
CD3: U1.50 (CD[3]), U2.35 (DQ3), U3.15 (DQ3), U7.6 (A4)
CD4: U1.51 (CD[4]), U2.38 (DQ4), U3.16 (DQ4), U7.7 (A5)
CD5: U1.52 (CD[5]), U2.40 (DQ5), U3.17 (DQ5), U7.8 (A6)
CD6: U1.53 (CD[6]), U2.42 (DQ6), U3.18 (DQ6), U7.9 (A7)
CD7: U1.54 (CD[7]), U2.44 (DQ7), U3.19 (DQ7), U7.10 (A8)
CH347_RST_N: R16.1, U10.3 (RST#)
CLK48: U1.11 (CLK48), X1.3 (OUT)
CONS_DIV: R1.2, R2.1, U1.13 (CONS_PRESENT)
EDGE_5V: C22.1, D1.2 (A), J1.1 (VCC), R1.1, TP1.1 (1_1), U7.23 (VCCB), U7.24 (VCCB)
FPGA_DONE: R6.1, U1.10 (DONE)
FPGA_JTAGSEL_N: R8.1, U1.4 (JTAGSEL_N)
FPGA_MODE0: R3.1, U1.88 (MODE0)
FPGA_MODE1: R4.1, U1.87 (MODE1)
FPGA_RECONFIG_N: R7.1, U1.9 (RECONFIG_N)
GB5_A0: J1.6 (A0), U4.2 (A1)
GB5_A1: J1.7 (A1), U4.3 (A2)
GB5_A2: J1.8 (A2), U4.4 (A3)
GB5_A3: J1.9 (A3), U4.5 (A4)
GB5_A4: J1.10 (A4), U4.6 (A5)
GB5_A5: J1.11 (A5), U4.7 (A6)
GB5_A6: J1.12 (A6), U4.8 (A7)
GB5_A7: J1.13 (A7), U4.9 (A8)
GB5_A8: J1.14 (A8), U5.2 (A1)
GB5_A9: J1.15 (A9), U5.3 (A2)
GB5_A10: J1.16 (A10), U5.4 (A3)
GB5_A11: J1.17 (A11), U5.5 (A4)
GB5_A12: J1.18 (A12), U5.6 (A5)
GB5_A13: J1.19 (A13), U5.7 (A6)
GB5_A14: J1.20 (A14), U5.8 (A7)
GB5_A15: J1.21 (A15), U5.9 (A8)
GB5_D0: J1.22 (D0), U7.21 (B1)
GB5_D1: J1.23 (D1), U7.20 (B2)
GB5_D2: J1.24 (D2), U7.19 (B3)
GB5_D3: J1.25 (D3), U7.18 (B4)
GB5_D4: J1.26 (D4), U7.17 (B5)
GB5_D5: J1.27 (D5), U7.16 (B6)
GB5_D6: J1.28 (D6), U7.15 (B7)
GB5_D7: J1.29 (D7), U7.14 (B8)
GB5_NCS: J1.5 (~CS), U6.4 (A3)
GB5_NRD: J1.4 (~RD), U6.3 (A2)
GB5_NRESET: J1.30 (~RESET), U6.5 (A4)
GB5_NWR: J1.3 (~WR), U6.2 (A1)
GB_A0: U1.25 (GB_A[0]), U4.18 (B1)
GB_A1: U1.26 (GB_A[1]), U4.17 (B2)
GB_A2: U1.27 (GB_A[2]), U4.16 (B3)
GB_A3: U1.28 (GB_A[3]), U4.15 (B4)
GB_A4: U1.29 (GB_A[4]), U4.14 (B5)
GB_A5: U1.30 (GB_A[5]), U4.13 (B6)
GB_A6: U1.31 (GB_A[6]), U4.12 (B7)
GB_A7: U1.32 (GB_A[7]), U4.11 (B8)
GB_A8: U1.33 (GB_A[8]), U5.18 (B1)
GB_A9: U1.34 (GB_A[9]), U5.17 (B2)
GB_A10: U1.35 (GB_A[10]), U5.16 (B3)
GB_A11: U1.36 (GB_A[11]), U5.15 (B4)
GB_A12: U1.37 (GB_A[12]), U5.14 (B5)
GB_A13: U1.38 (GB_A[13]), U5.13 (B6)
GB_A14: U1.39 (GB_A[14]), U5.12 (B7)
GB_A15: U1.40 (GB_A[15]), U5.11 (B8)
GB_AUDIO: J1.31 (AUDIO_IN), TP6.1 (1_1)
GB_CLK: J1.2 (CLK), TP5.1 (1_1)
GB_NCS: U1.16 (GB_NCS), U6.16 (B3)
GB_NRD: U1.42 (GB_NRD), U6.17 (B2)
GB_NRESET: U1.17 (GB_NRESET), U6.15 (B4)
GB_NWR: U1.41 (GB_NWR), U6.18 (B1)
GND: C1.2, C2.2, C3.2, C4.2, C5.2, C6.2, C7.2, C8.2, C9.2, C10.2, C11.2, C12.2, C13.2, C14.2, C15.2, C16.2, C17.2, C18.2, C19.2, C20.2, C21.2, C22.2, C23.2, C24.2, C25.2, C26.2, C27.2, J1.32 (GND), J2.A1 (GND), J2.A12 (GND), J2.B1 (GND), J2.B12 (GND), J2.SH (SHIELD), R2.2, R3.2, R4.2, R5.2, R17.2, R18.2, TP4.1 (1_1), U1.2 (VSS), U1.21 (VSS), U1.24 (VSS), U1.43 (VSS), U1.46 (VSS), U1.65 (VSS), U1.89 (EP), U2.27 (VSS), U2.46 (VSS), U2.47 (BYTE#), U3.14 (VSS), U4.10 (GND), U4.19 (OE#), U5.10 (GND), U5.19 (OE#), U6.6 (A5), U6.7 (A6), U6.8 (A7), U6.9 (A8), U6.10 (GND), U6.19 (OE#), U7.11 (GND), U7.12 (GND), U7.13 (GND), U8.1 (VSS), U9.2 (VSS), U10.20 (GND), U10.29 (GND), U11.2 (GND), X1.2 (GND), Y1.2 (GND), Y1.4 (GND)
JTAG_TCK: R5.1, U1.6 (TCK), U10.23 (TCK)
JTAG_TDI: U1.7 (TDI), U10.25 (TDI)
JTAG_TDO: U1.8 (TDO), U10.24 (TDO)
JTAG_TMS: U1.5 (TMS), U10.26 (TMS)
MA0: U1.59 (MA[0]), U2.45 (DQ15/A-1), U3.10 (A0)
MA1: U1.60 (MA[1]), U2.25 (A0), U3.9 (A1)
MA2: U1.61 (MA[2]), U2.24 (A1), U3.8 (A2)
MA3: U1.62 (MA[3]), U2.23 (A2), U3.7 (A3)
MA4: U1.63 (MA[4]), U2.22 (A3), U3.6 (A4)
MA5: U1.68 (MA[5]), U2.21 (A4), U3.5 (A5)
MA6: U1.69 (MA[6]), U2.20 (A5), U3.4 (A6)
MA7: U1.70 (MA[7]), U2.19 (A6), U3.3 (A7)
MA8: U1.71 (MA[8]), U2.18 (A7), U3.25 (A8)
MA9: U1.72 (MA[9]), U2.8 (A8), U3.24 (A9)
MA10: U1.73 (MA[10]), U2.7 (A9), U3.21 (A10)
MA11: U1.74 (MA[11]), U2.6 (A10), U3.23 (A11)
MA12: U1.75 (MA[12]), U2.5 (A11), U3.2 (A12)
MA13: U1.76 (MA[13]), U2.4 (A12), U3.26 (A13)
MA14: U1.77 (MA[14]), U2.3 (A13), U3.1 (A14)
MA15: U1.79 (MA[15]), U2.2 (A14)
MA16: U1.80 (MA[16]), U2.1 (A15)
MA17: U1.81 (MA[17]), U2.48 (A16)
MA18: U1.82 (MA[18]), U2.17 (A17)
MA19: U1.83 (MA[19]), U2.16 (A18)
MA20: U1.84 (MA[20]), U2.9 (A19)
MA21: U1.85 (MA[21]), U2.10 (A20)
MA22: U1.86 (MA[22]), U2.13 (A21)
MEM_NOE: U1.55 (MEM_NOE), U2.28 (OE#), U3.22 (OE#)
RAM_NCE: R11.1, U1.3 (RAM_NCE), U3.20 (CE#)
RAM_NWE: R13.1, U1.57 (RAM_NWE), U3.27 (WE#)
ROM_NCE: R10.1, U1.20 (ROM_NCE), U2.26 (CE#)
ROM_NWE: R12.1, U1.56 (ROM_NWE), U2.11 (WE#)
ROM_RESET_N: R14.1, U2.12 (RESET#)
ROM_WP_N: R15.1, U2.14 (WP#/ACC)
UART_TO_FPGA: U1.14 (UART_RX), U10.19 (TXD0)
UART_TO_USB: U1.15 (UART_TX), U10.22 (RXD0)
USB_CC1: J2.A5 (CC1), R17.1
USB_CC2: J2.B5 (CC2), R18.1
USB_DN: J2.A7 (DN1), J2.B7 (DN2), U10.27 (UD-), U11.3 (I/O2), U11.4 (I/O2)
USB_DP: J2.A6 (DP1), J2.B6 (DP2), U10.28 (UD+), U11.1 (I/O1), U11.6 (I/O1)
USB_VBUS: D2.2 (A), J2.A4 (VBUS), J2.A9 (VBUS), J2.B4 (VBUS), J2.B9 (VBUS), U11.5 (VBUS)
VSYS: C12.1, C15.1, D1.1 (K), D2.1 (K), U8.3 (VIN)
XTAL_XI: C25.1, U10.1 (XI), Y1.1
XTAL_XO: C26.1, U10.2 (XO), Y1.3

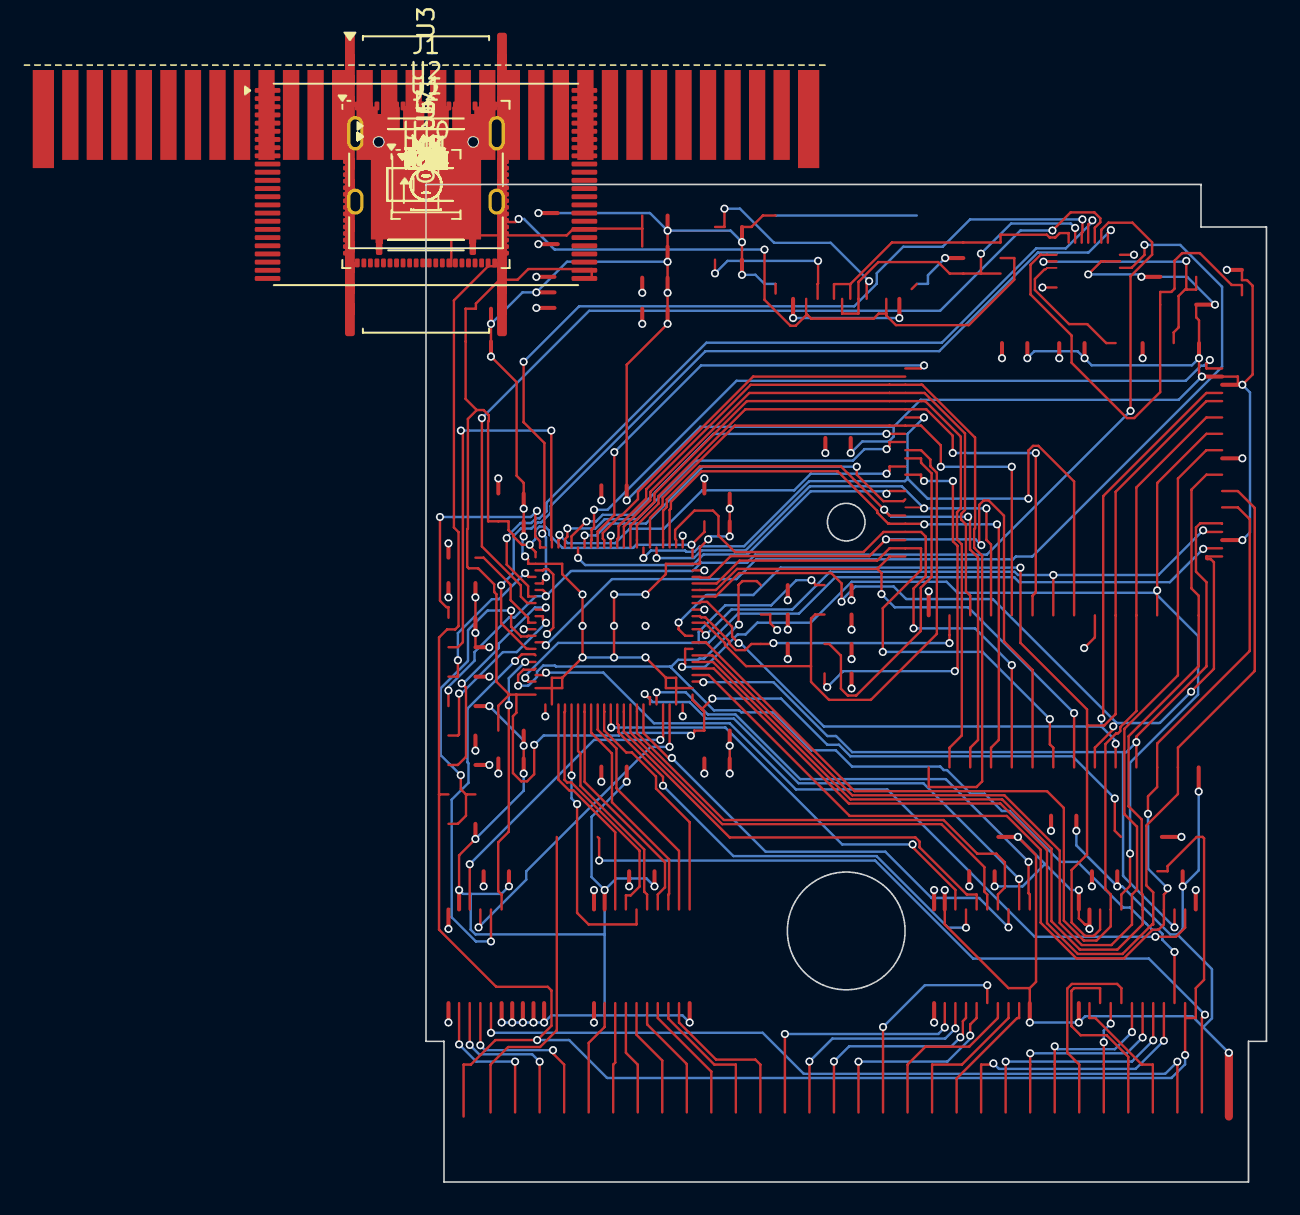
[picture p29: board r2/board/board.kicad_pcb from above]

Board: 4 copper layers, 51.4 x 61.0 mm, 68 parts (0 on the bottom side), 116 nets.

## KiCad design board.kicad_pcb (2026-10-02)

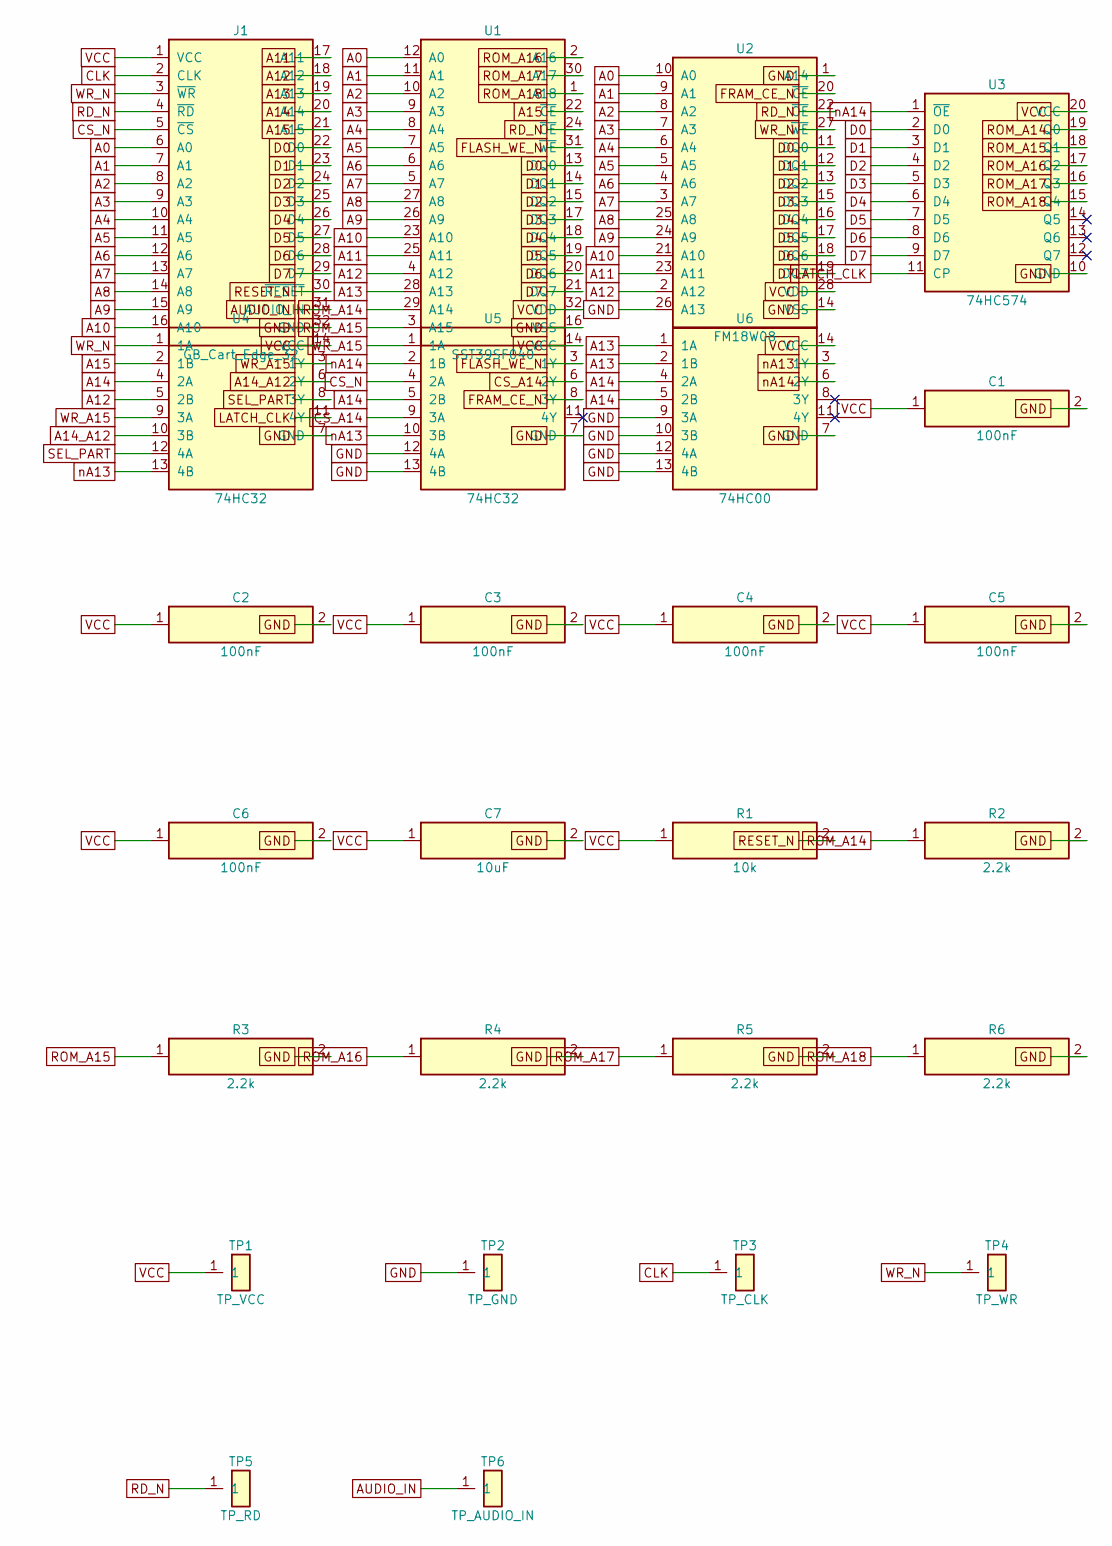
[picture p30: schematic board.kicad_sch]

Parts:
C1, C2, C3, C4, C5, C6: 100nF; C_0603_1608Metric; MPN CC0603KRX7R9BB104; LCSC C14663
C7: 10uF; C_1206_3216Metric; MPN CL31A106KBHNNNE; LCSC C13585
J1: GB_Cart_Edge_32; GB_Cart_Edge_32_DMG
R1: 10k; R_0603_1608Metric; MPN 0603WAF1002T5E; LCSC C25804
R2, R3, R4, R5, R6: 2.2k; R_0603_1608Metric; MPN 0603WAF2201T5E; LCSC C4190
TP1: TP_VCC; TestPoint_Pad_D1.5mm
TP2: TP_GND; TestPoint_Pad_D1.5mm
TP3: TP_CLK; TestPoint_Pad_D1.5mm
TP4: TP_WR; TestPoint_Pad_D1.5mm
TP5: TP_RD; TestPoint_Pad_D1.5mm
TP6: TP_AUDIO_IN; TestPoint_Pad_D1.5mm
U1: SST39SF040; PLCC-32_11.4x14.0mm_P1.27mm; MPN SST39SF040-55-4I-NHE-T; LCSC C632847
U2: FM18W08; SOIC-28W_7.5x17.9mm_P1.27mm; MPN FM18W08-SGTR; LCSC C55945
U3: 74HC574; SOIC-20W_7.5x12.8mm_P1.27mm; MPN SN74HC574DWR; LCSC C10097
U4, U5: 74HC32; SOIC-14_3.9x8.7mm_P1.27mm; MPN SN74HC32DR; LCSC C6838
U6: 74HC00; SOIC-14_3.9x8.7mm_P1.27mm; MPN SN74HC00DR; LCSC C10090

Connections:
A0: J1.6 (A0), U1.12 (A0), U2.10 (A0)
A1: J1.7 (A1), U1.11 (A1), U2.9 (A1)
A2: J1.8 (A2), U1.10 (A2), U2.8 (A2)
A3: J1.9 (A3), U1.9 (A3), U2.7 (A3)
A4: J1.10 (A4), U1.8 (A4), U2.6 (A4)
A5: J1.11 (A5), U1.7 (A5), U2.5 (A5)
A6: J1.12 (A6), U1.6 (A6), U2.4 (A6)
A7: J1.13 (A7), U1.5 (A7), U2.3 (A7)
A8: J1.14 (A8), U1.27 (A8), U2.25 (A8)
A9: J1.15 (A9), U1.26 (A9), U2.24 (A9)
A10: J1.16 (A10), U1.23 (A10), U2.21 (A10)
A11: J1.17 (A11), U1.25 (A11), U2.23 (A11)
A12: J1.18 (A12), U1.4 (A12), U2.2 (A12), U4.5 (2B)
A13: J1.19 (A13), U1.28 (A13), U6.1 (1A), U6.2 (1B)
A14: J1.20 (A14), U4.4 (2A), U5.5 (2B), U6.4 (2A), U6.5 (2B)
A14_A12: U4.6 (2Y), U4.10 (3B)
A15: J1.21 (A15), U1.22 (~CE), U4.2 (1B)
AUDIO_IN: J1.31 (AUDIO_IN), TP6.1 (1_1)
CLK: J1.2 (CLK), TP3.1 (1_1)
CS_A14: U5.6 (2Y), U5.9 (3A)
CS_N: J1.5 (~CS), U5.4 (2A)
D0: J1.22 (D0), U1.13 (DQ0), U2.11 (DQ0), U3.2 (D0)
D1: J1.23 (D1), U1.14 (DQ1), U2.12 (DQ1), U3.3 (D1)
D2: J1.24 (D2), U1.15 (DQ2), U2.13 (DQ2), U3.4 (D2)
D3: J1.25 (D3), U1.17 (DQ3), U2.15 (DQ3), U3.5 (D3)
D4: J1.26 (D4), U1.18 (DQ4), U2.16 (DQ4), U3.6 (D4)
D5: J1.27 (D5), U1.19 (DQ5), U2.17 (DQ5), U3.7 (D5)
D6: J1.28 (D6), U1.20 (DQ6), U2.18 (DQ6), U3.8 (D6)
D7: J1.29 (D7), U1.21 (DQ7), U2.19 (DQ7), U3.9 (D7)
FLASH_WE_N: U1.31 (~WE), U5.3 (1Y)
FRAM_CE_N: U2.20 (~CE), U5.8 (3Y)
GND: C1.2, C2.2, C3.2, C4.2, C5.2, C6.2, C7.2, J1.32 (GND), R2.2, R3.2, R4.2, R5.2, R6.2, TP2.1 (1_1), U1.16 (VSS), U2.1 (A14), U2.14 (VSS), U2.26 (A13), U3.10 (GND), U4.7 (GND), U5.7 (GND), U5.12 (4A), U5.13 (4B), U6.7 (GND), U6.9 (3A), U6.10 (3B), U6.12 (4A), U6.13 (4B)
LATCH_CLK: U3.11 (CP), U4.11 (4Y)
RD_N: J1.4 (~RD), TP5.1 (1_1), U1.24 (~OE), U2.22 (~OE)
RESET_N: J1.30 (~RESET), R1.2
ROM_A14: R2.1, U1.29 (A14), U3.19 (Q0)
ROM_A15: R3.1, U1.3 (A15), U3.18 (Q1)
ROM_A16: R4.1, U1.2 (A16), U3.17 (Q2)
ROM_A17: R5.1, U1.30 (A17), U3.16 (Q3)
ROM_A18: R6.1, U1.1 (A18), U3.15 (Q4)
SEL_PART: U4.8 (3Y), U4.12 (4A)
VCC: C1.1, C2.1, C3.1, C4.1, C5.1, C6.1, C7.1, J1.1 (VCC), R1.1, TP1.1 (1_1), U1.32 (VDD), U2.28 (VDD), U3.20 (VCC), U4.14 (VCC), U5.14 (VCC), U6.14 (VCC)
WR_A15: U4.3 (1Y), U4.9 (3A), U5.1 (1A)
WR_N: J1.3 (~WR), TP4.1 (1_1), U2.27 (~WE), U4.1 (1A)
nA13: U4.13 (4B), U5.10 (3B), U6.3 (1Y)
nA14: U3.1 (~OE), U5.2 (1B), U6.6 (2Y)

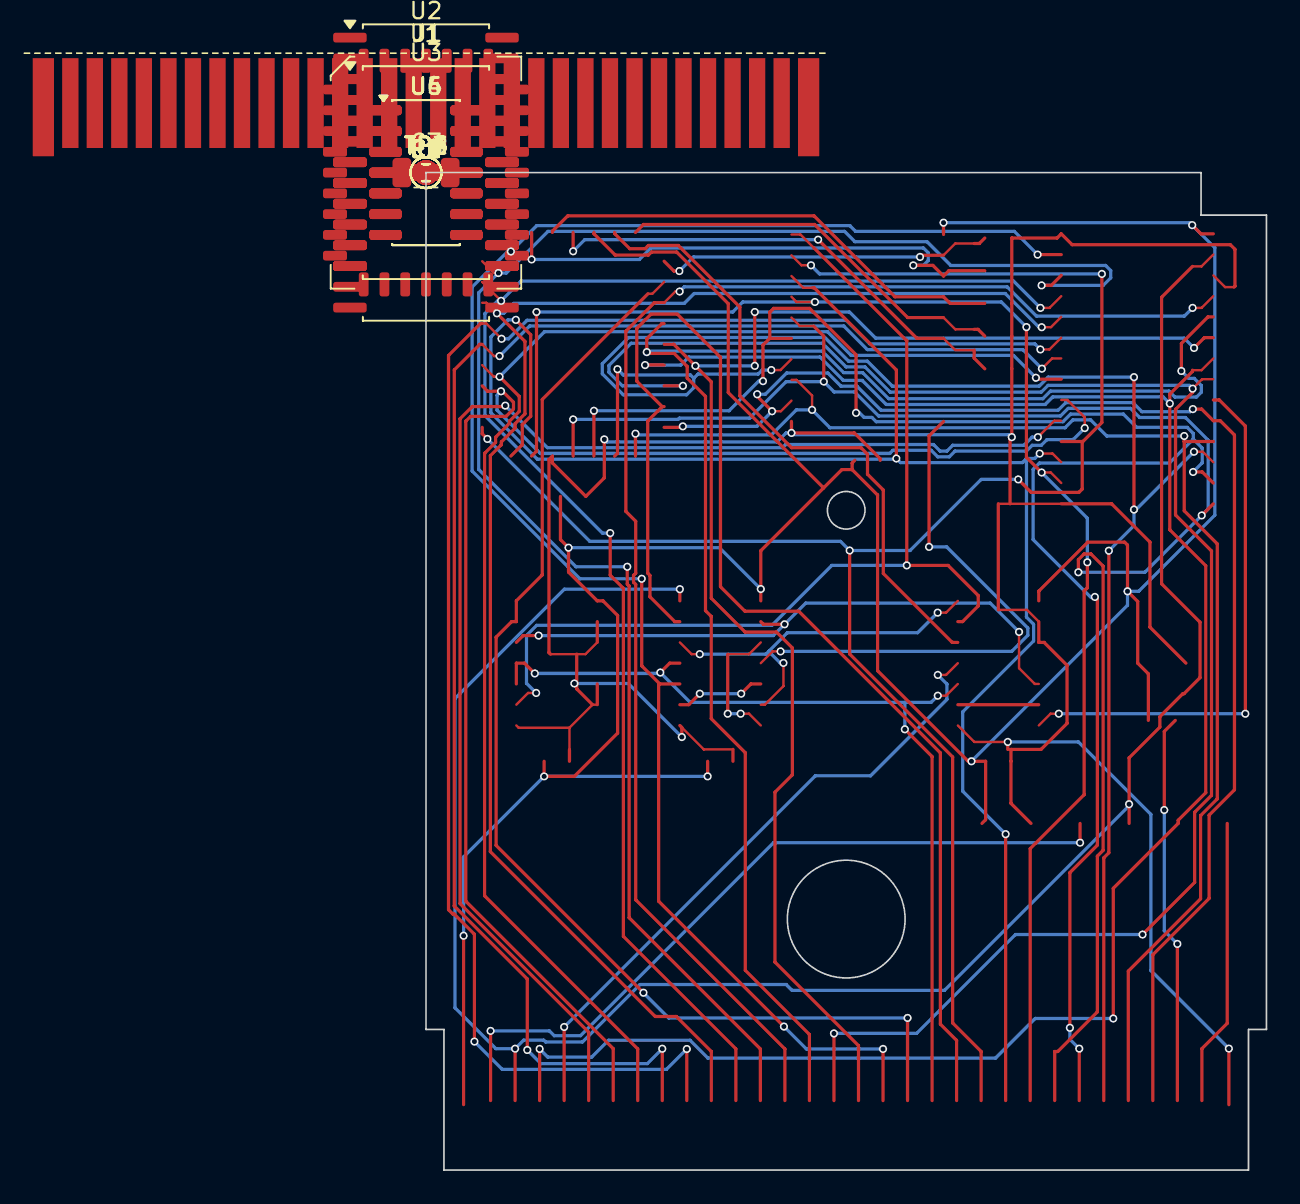
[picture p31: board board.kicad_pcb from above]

Board: 2 copper layers, 51.4 x 61.0 mm, 26 parts (0 on the bottom side), 46 nets.

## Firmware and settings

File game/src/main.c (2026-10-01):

// Bit Catcher — tiny homebrew game for the GB DEVCART r1 (GBDK-2020).
//
// Catch the falling cartridges with the paddle, dodge the bugs. Missing a cartridge or catching a
// bug costs a life; the high score is kept in the cart's F-RAM (no battery needed).
#include <gb/gb.h>
#include <gbdk/console.h>
#include <rand.h>
#include <stdint.h>
#include <stdio.h>

// ---- cart glue --------------------------------------------------------------------------------
// The devcart's 74HC574 bank latch powers up random. Bank 0 (0x0000-0x3FFF) is fixed, so select
// bank 1 before anything touches 0x4000-0x7FFF. Everything in this game lives in bank 0, and the
// write is also what an MBC5 expects, so the ROM runs the same in emulators.
#define BANK_REG (*(volatile uint8_t *)0x2000)

// High score in F-RAM (0xA000). The devcart's F-RAM is always enabled; the 0x0A write to 0x0000
// is for MBC5 emulators and is ignored by the devcart's decoder.
#define SRAM ((volatile uint8_t *)0xA000)  // [0..3] = "GBDC", [4..5] = high score (LE)
static const uint8_t magic[4] = {'G', 'B', 'D', 'C'};

static uint16_t load_hiscore(void) {
  uint16_t hi = 0;
  uint8_t ok = 1;
  ENABLE_RAM;
  for (uint8_t i = 0; i < 4; i++)
    if (SRAM[i] != magic[i]) ok = 0;
  if (ok) hi = SRAM[4] | ((uint16_t)SRAM[5] << 8);
  DISABLE_RAM;
  return hi;
}

static void store_hiscore(uint16_t hi) {
  ENABLE_RAM;
  for (uint8_t i = 0; i < 4; i++) SRAM[i] = magic[i];
  SRAM[4] = (uint8_t)hi;
  SRAM[5] = (uint8_t)(hi >> 8);
  DISABLE_RAM;
}

// ---- graphics (2bpp, colour 3 = both planes set) ----------------------------------------------
static const uint8_t sprite_tiles[] = {
    // 0: paddle segment
    0x00, 0x00, 0x00, 0x00, 0x00, 0x00, 0x00, 0x00, 0xFF, 0x00, 0xFF, 0xFF, 0xFF, 0xFF, 0x00, 0xFF,
    // 1: cartridge
    0x7C, 0x7C, 0x44, 0x7C, 0x54, 0x7C, 0x44, 0x7C, 0x7C, 0x7C, 0x7C, 0x7C, 0x54, 0x54, 0x54, 0x54,
    // 2: bug
    0x24, 0x24, 0x18, 0x18, 0x7E, 0x7E, 0xDB, 0xFF, 0x7E, 0x7E, 0x3C, 0x3C, 0x66, 0x66, 0x42, 0x42,
};
#define T_PADDLE 0
#define T_CART 1
#define T_BUG 2

// ---- game state ---------------------------------------------------------------------------------
#define PADDLE_SPRITES 3
#define PADDLE_W 24
#define PADDLE_Y 136  // screen y of the paddle bar
#define N_OBJ 4
#define FIRST_OBJ_SPRITE PADDLE_SPRITES

typedef struct {
  uint8_t active, kind, x;
  uint16_t y;  // 1/16 pixel
} obj_t;

static obj_t objs[N_OBJ];
static uint8_t paddle_x;
static uint16_t score, hiscore;
static uint8_t lives, speed, spawn_timer;

static void draw_hud(void) {
  gotoxy(0, 0);
  printf("SCORE %u  HI %u   ", score, hiscore);
  gotoxy(0, 1);
  printf("LIVES %u           ", (uint16_t)lives);
}

static void place_paddle(void) {
  for (uint8_t i = 0; i < PADDLE_SPRITES; i++) move_sprite(i, paddle_x + 8 + i * 8, PADDLE_Y + 16 - 4);
}

static void hide_obj(uint8_t i) {
  objs[i].active = 0;
  move_sprite(FIRST_OBJ_SPRITE + i, 0, 0);
}

static void spawn(void) {
  for (uint8_t i = 0; i < N_OBJ; i++) {
    if (objs[i].active) continue;
    objs[i].active = 1;
    objs[i].kind = (rand() & 3) == 0 ? T_BUG : T_CART;  // 1 in 4 is a bug
    objs[i].x = 8 + (uint8_t)(rand() % 144);
    objs[i].y = (uint16_t)24 << 4;
    set_sprite_tile(FIRST_OBJ_SPRITE + i, objs[i].kind);
    return;
  }
}

static void wait_start(void) {
  while (!(joypad() & J_START)) vsync();
  while (joypad() & J_START) vsync();
}

static void title(void) {
  HIDE_SPRITES;
  cls();
  gotoxy(4, 4);  printf("BIT CATCHER");
  gotoxy(2, 6);  printf("GB DEVCART r1 demo");
  gotoxy(2, 9);  printf("catch the carts,");
  gotoxy(2, 10); printf("dodge the bugs!");
  gotoxy(4, 13); printf("HI SCORE %u", hiscore);
  gotoxy(4, 16); printf("PRESS START");
  wait_start();
  initrand(DIV_REG);
}

static void play(void) {
  cls();
  score = 0; lives = 3; speed = 12; spawn_timer = 30;
  paddle_x = 68;
  for (uint8_t i = 0; i < N_OBJ; i++) hide_obj(i);
  place_paddle();
  SHOW_SPRITES;
  draw_hud();

  while (lives) {
    uint8_t keys = joypad();
    if ((keys & J_LEFT) && paddle_x > 2) paddle_x -= 2;
    if ((keys & J_RIGHT) && paddle_x < 160 - PADDLE_W - 2) paddle_x += 2;
    place_paddle();

    if (--spawn_timer == 0) {
      spawn();
      spawn_timer = (uint8_t)(40 - (speed > 36 ? 36 : speed));
    }

    uint8_t hud_dirty = 0;
    for (uint8_t i = 0; i < N_OBJ; i++) {
      if (!objs[i].active) continue;
      objs[i].y += speed;
      uint8_t sy = (uint8_t)(objs[i].y >> 4);
      uint8_t ox = objs[i].x;
      if (sy + 8 >= PADDLE_Y && sy <= PADDLE_Y + 4 && ox + 6 >= paddle_x && ox <= paddle_x + PADDLE_W - 2) {
        if (objs[i].kind == T_CART) {
          score++;
          if ((score & 7) == 0 && speed < 48) speed += 2;  // faster every 8 catches
        } else {
          lives--;
        }
        hide_obj(i);
        hud_dirty = 1;
      } else if (sy > 144) {
        if (objs[i].kind == T_CART) { lives--; hud_dirty = 1; }
        hide_obj(i);
      } else {
        move_sprite(FIRST_OBJ_SPRITE + i, ox + 8, sy + 16);
      }
    }
    if (hud_dirty) draw_hud();
    vsync();
  }

  for (uint8_t i = 0; i < N_OBJ; i++) hide_obj(i);
  if (score > hiscore) {
    hiscore = score;
    store_hiscore(hiscore);
  }
  gotoxy(5, 8);  printf("GAME OVER");
  gotoxy(4, 10); printf("SCORE %u", score);
  gotoxy(3, 13); printf("PRESS START");
  wait_start();
}

void main(void) {
  BANK_REG = 1;

  DISPLAY_OFF;
  set_sprite_data(0, 3, sprite_tiles);
  for (uint8_t i = 0; i < PADDLE_SPRITES; i++) set_sprite_tile(i, T_PADDLE);
  OBP0_REG = 0xE4;
  BGP_REG = 0xE4;
  SHOW_BKG;
  DISPLAY_ON;

  hiscore = load_hiscore();
  for (;;) {
    title();
    play();
  }
}

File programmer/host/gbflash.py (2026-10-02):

#!/usr/bin/env python3
"""gbflash — flash, dump and back up the GB DEVCART r1 over USB (Arduino Mega programmer).

    pip install pyserial
    python3 gbflash.py --port /dev/ttyACM0 info
    python3 gbflash.py --port /dev/ttyACM0 flash game.gb          # erase, program, verify
    python3 gbflash.py --port /dev/ttyACM0 dump backup.gb [--size 524288]
    python3 gbflash.py --port /dev/ttyACM0 save-backup game.sav   # 8 KB F-RAM at 0xA000
    python3 gbflash.py --port /dev/ttyACM0 save-restore game.sav
    python3 gbflash.py --port /dev/ttyACM0 --rev 2 flash big.gb      # r2 through the Mega
    python3 gbflash.py --usb /dev/ttyACM0 flash big.gb               # r2 on its own USB-C port

`--sim path/to/cart_sim [--sim-flash f.bin --sim-fram r.bin]` runs the same protocol against the native cart simulator instead of a
serial port (used by programmer/test_e2e.sh).
"""
from __future__ import annotations

import argparse
import os
import struct
import subprocess
import sys
import time

FLASH_SIZE = 512 * 1024      # r1: SST39SF040
FLASH_SIZE_R2 = 8 * 1024 * 1024  # r2: S29GL064 (x8)
BANK_SIZE = 0x4000
SAVE_SIZE = 0x2000
CHUNK = 256
KNOWN_FLASH = {(0x01, 0x7E): "S29GL064N (8 MB, r2)", (0xBF, 0xB7): "SST39SF040 (512 KB)", (0xBF, 0xB6): "SST39SF020A (256 KB)", (0xBF, 0xB5): "SST39SF010A (128 KB)"}


class Link:
    def __init__(self, port: str | None, sim: str | None, sim_args: list[str], rev: int = 1):
        self.rev = rev
        if sim:
            env = {**os.environ, "GBCART_REV": str(rev)}
            self.proc = subprocess.Popen([sim, *sim_args], stdin=subprocess.PIPE, stdout=subprocess.PIPE, env=env)
            self._w, self._r = self.proc.stdin, self.proc.stdout
        else:
            import serial  # pyserial

            self.proc = None
            self.ser = serial.Serial(port, 1_000_000, timeout=5)
            time.sleep(2.0)  # the Mega resets when the port opens
            self.ser.reset_input_buffer()
            self._w = self._r = None

    def write(self, data: bytes) -> None:
        if self.proc:
            self._w.write(data)
            self._w.flush()
        else:
            self.ser.write(data)

    def read(self, n: int) -> bytes:
        buf = self._r.read(n) if self.proc else self.ser.read(n)
        if len(buf) != n:
            raise IOError(f"programmer timed out ({len(buf)}/{n} bytes)")
        return buf

    def status(self, what: str) -> None:
        s = self.read(1)
        if s != b"K":
            raise IOError(f"{what} failed: {s!r} ({'timeout' if s == b'T' else 'verify mismatch' if s == b'F' else 'protocol error'})")

    def close(self) -> None:
        if self.proc:
            self._w.close()
            self.proc.wait(timeout=30)
        else:
            self.ser.close()

    # --- commands -------------------------------------------------------------------------
    def hello(self) -> str:
        self.write(b"I")
        line = self.read(9)
        if line != b"GBFLASH1\n":
            raise IOError(f"unexpected greeting {line!r}: is gbflash.ino flashed to the Mega?")
        return line.decode().strip()

    def flash_id(self) -> tuple[int, int]:
        self.write(b"D")
        m, d = self.read(2)
        return m, d

    def set_rev(self) -> None:
        """Tell the firmware which cart this is; r2 also enters the mapper's dev mode."""
        self.write(b"V" + bytes([self.rev]))
        self.status("cart revision")

    def leave_dev_mode(self) -> None:
        if self.rev == 2:
            self.write_bus(0x0000, b"\xD0")

    def bank(self, n: int) -> None:
        if self.rev == 2:
            self.write(b"b" + struct.pack("<H", n))
        else:
            self.write(b"B" + bytes([n & 0xFF]))
        self.status("bank select")

    def read_bus(self, addr: int, n: int) -> bytes:
        self.write(b"R" + struct.pack("<HH", addr, n))
        return self.read(n)

    def write_bus(self, addr: int, data: bytes) -> None:
        self.write(b"W" + struct.pack("<HH", addr, len(data)) + data)
        self.status("bus write")

    def chip_erase(self) -> None:
        self.write(b"E")
        if not self.proc:
            self.ser.timeout = 320  # 8 MB parts take tens of seconds, up to a few minutes
        try:
            self.status("chip erase")
        finally:
            if not self.proc:
                self.ser.timeout = 5

    def program(self, fa: int, data: bytes) -> None:
        self.write(b"P" + struct.pack("<I", fa)[:3] + struct.pack("<H", len(data)) + data)
        self.status(f"program @0x{fa:05x}")


def read_flash(link: Link, size: int) -> bytes:
    out = bytearray(link.read_bus(0x0000, BANK_SIZE))  # bank 0, fixed window
    for bank in range(1, size // BANK_SIZE):
        link.bank(bank)
        out += link.read_bus(0x4000, BANK_SIZE)
    return bytes(out[:size])


def progress(done: int, total: int, label: str) -> None:
    pct = done * 100 // max(total, 1)
    sys.stderr.write(f"\r{label} {pct:3d}% ({done}/{total} bytes)")
    if done >= total:
        sys.stderr.write("\n")


def header_info(rom: bytes) -> str:
    title = rom[0x134:0x144].split(b"\0")[0].decode("ascii", "replace")
    chk = (-sum(rom[0x134:0x14D]) - 25) & 0xFF  # header checksum: x = x - b - 1 over 0x134..0x14C
    ok = "ok" if chk == rom[0x14D] else f"BAD (expected 0x{chk:02x})"
    return f"title={title!r} type=0x{rom[0x147]:02x} rom_size_code=0x{rom[0x148]:02x} header_checksum={ok}"


def flash_size(link: Link) -> int:
    return FLASH_SIZE_R2 if link.rev == 2 else FLASH_SIZE


def read_save(link: Link) -> bytes:
    if link.rev != 2:
        return link.read_bus(0xA000, SAVE_SIZE)
    link.leave_dev_mode()            # RAM-bank writes are ignored in dev mode
    link.write_bus(0x0000, b"\x0A")  # MBC5 RAM enable
    out = b""
    for bank in range(4):            # 4 x 8 KB = the whole 32 KB F-RAM
        link.write_bus(0x4000, bytes([bank]))
        out += link.read_bus(0xA000, SAVE_SIZE)
    return out


def write_save(link: Link, data: bytes) -> None:
    if link.rev == 2:
        link.leave_dev_mode()
        link.write_bus(0x0000, b"\x0A")
    for base in range(0, len(data), SAVE_SIZE):
        if link.rev == 2:
            link.write_bus(0x4000, bytes([base // SAVE_SIZE]))
        part = data[base : base + SAVE_SIZE]
        for off in range(0, len(part), CHUNK):
            link.write_bus(0xA000 + off, part[off : off + CHUNK])
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

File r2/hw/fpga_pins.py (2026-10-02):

#!/usr/bin/env python3
"""Single source of truth for the GW1N-LV4QN88 pin assignment of GB DEVCART r2.

Writes r2/gw1n4_qn88.cst (FPGA constraints) and r2/hw/fpga_pins.json (used by the netlist
generator), so the FPGA build and the PCB can never disagree.

Package sides (QN88, pin 1 top-left, counter-clockwise): left 1-22, bottom 23-44, right 45-66,
top 67-88. Config pins kept dedicated: JTAGSEL_N 4, TMS 5, TCK 6, TDI 7, TDO 8, RECONFIG_N 9,
DONE 10, MODE1 87, MODE0 88. Power: see docs/r2-pinouts.json.
"""
import json
from pathlib import Path

HERE = Path(__file__).resolve().parent
LEFT = [3, 11, 13, 14, 15, 16, 17, 18, 19, 20]
BOTTOM = list(range(25, 43))
RIGHT_TOP = [47, 48, 49, 50, 51, 52, 53, 54, 55, 56, 57, 59, 60, 61, 62, 63,
             68, 69, 70, 71, 72, 73, 74, 75, 76, 77, 79, 80, 81, 82, 83, 84, 85, 86]

pins: dict[str, int] = {}
# left: clock (GCLKT_6 on pin 11), USB UART, console-side control, chip enables
for name, pin in zip(["RAM_NCE", "CLK48", "CONS_PRESENT", "UART_RX", "UART_TX", "GB_NCS",
                      "GB_NRESET", "BUS_NOE", "BUS_DIR", "ROM_NCE"], LEFT):
    pins[name] = pin
# bottom: console address bus and strobes, facing the level shifters / edge fingers
for name, pin in zip([f"GB_A[{i}]" for i in range(16)] + ["GB_NWR", "GB_NRD"], BOTTOM):
    pins[name] = pin
# right + top: memory side, facing flash / F-RAM
mem = [f"CD[{i}]" for i in range(8)] + ["MEM_NOE", "ROM_NWE", "RAM_NWE"] + [f"MA[{i}]" for i in range(23)]
for name, pin in zip(mem, RIGHT_TOP):
    pins[name] = pin

assert len(pins) == 62 and len(set(pins.values())) == 62, len(pins)

with open(HERE.parent / "gw1n4_qn88.cst", "w") as f:
    f.write("// GB DEVCART r2 — GW1N-LV4QN88 pin constraints, generated by r2/hw/fpga_pins.py\n")
    f.write("// All banks VCCIO = 3.3 V. JTAG / MODE / DONE / RECONFIG_N kept dedicated.\n")
    for name, pin in pins.items():
        pull = " PULL_MODE=UP" if name in ("CONS_PRESENT",) else ""
        f.write(f'IO_LOC "{name}" {pin};\nIO_PORT "{name}" IO_TYPE=LVCMOS33{pull};\n')
json.dump(pins, open(HERE / "fpga_pins.json", "w"), indent=1)
print(f"wrote gw1n4_qn88.cst and hw/fpga_pins.json ({len(pins)} pins)")

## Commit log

2026-10-01 GB devcart r1: placed, DRC/ERC-clean board generated with fabdesk + Claude Code
    Open Game Boy / ModRetro Chromatic homebrew dev cartridge: SST39SF040 flash,
    discrete MBC5-subset bank latch, FM18W08 F-RAM saves. Unrouted (no router
    available in the build environment).
    Claude-Session: https://claude.ai/code/session_01K74FFAntk76NicGJzRejN5
    [board.kicad_pcb, board.kicad_sch]
2026-10-01 Add 3D models, USB programmer, Bit Catcher demo game
    - Vendor 3D models for every part (KiCad library STEP + generated PLCC-32) and point the
    board at ${KIPRJMOD}/3dmodels; GLB/STEP exports and three.js renders in the README.
    - programmer/: Arduino Mega 2560 USB flasher (firmware + gbflash.py host tool) with a
    portable protocol core, a native simulator of this cart and an end-to-end test.
    - game/: Bit Catcher, a GBDK-2020 homebrew game with an F-RAM high score and a PyBoy test.
    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
    [C_0603_1608Metric.step, C_1206_3216Metric.step, PLCC-32_11.4x14.0mm_P1.27mm.step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]
2026-10-01 Switch to in-stock JLCPCB/LCSC parts; add JLC export script
    U1 SST39SF040-55-4I-NHE-T (C632847) and U2 FM18W08-SGTR (C55945) replace the
    out-of-stock -70-4C-NHE and -SG; every assembled part now carries MPN + LCSC
    fields in circuit.netlist.json and scripts/gen.py. scripts/jlc_export.py writes
    gerbers.zip, bom.csv and cpl.csv for JLC assembly.
    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
2026-10-02 Route the board with Freerouting; JLC part fields and order files
    - Fully routed 2-layer board (134/134 connections) from fabdesk's route_run
    with Freerouting 2.4.1; DRC 0 errors / 0 unconnected, ERC clean. Placement
    tweaks (U2, U3, C2, C3, C6, R2-R6) and rules (0.2 mm track, 0.15 mm
    clearance, 0.5/0.3 mm vias) mirrored in circuit.netlist.json and gen.py.
    - MPN / Manufacturer / LCSC on all 19 assembled parts in the board and
    schematic (scripts/sync_fields.py).
    - exports/jlcpcb: gerbers.zip, bom.csv, cpl.csv (scripts/jlc_export.py).
    - Refreshed GLB/STEP exports, 3D and routing renders, README status.
    Claude-Session: https://clau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
    [board.kicad_pcb, board.kicad_sch, board.step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]
2026-10-02 r2: FPGA mapper (MBC5 + locked dev mode) for GW1NZ-LV1 with testbench
    gbcart_mapper.v implements MBC5 (9-bit ROM bank, RAM enable, 4 RAM banks)
    plus a dev mode entered by writing "GBDV" to 6000-7FFF that routes writes in
    4000-7FFF to the flash /WE. Writes are sampled on an on-chip 41.7 MHz clock
    from a 4-deep history so the committed value predates the /WR edge. The
    testbench drives GB bus cycles into flash/F-RAM models and passes at /WR
    widths 480-100 ns. Open-source flow (yosys, nextpnr-himbaechel, apicula):
    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
2026-10-02 r2: move to GW1N-LV4QN88 + USB mode; FPGA drives the memories
    - gbcart_mapper: full 23-bit memory address and all memory strobes from the
    FPGA; usb_mode hands the memory side to the USB engine.
    - usb_engine: UART (1 Mbaud) commands I/M/R/W/P; P buffers up to 256 bytes in
    BSRAM and programs flash with the AMD write-buffer sequence + Data# polling.
    - gbcart_core: console-present debounce; mapper held in reset in USB mode.
    - top_gw1n4 + gw1n4_qn88.cst from r2/hw/fpga_pins.py (62 I/O, 48 MHz ext clock).
    - Testbench: console MBC5/dev-mode checks plus USB I/M/R/W/P against flash
    (incl. write buffer, busy polling) and F-RAM models; passes at 480/240/150 ns.
    - P&R on GW1N-LV4QN88: 968 LUT4, 36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
    [fpga_pins.py, usb_engine.v]
2026-10-02 r2: program the cart over its own USB-C port (gbflash.py --usb)
    gbusb.UsbCart speaks the FPGA USB-engine protocol (I/M/R/W/P) through the
    CH347F UART and implements the S29GL064 algorithms host-side (autoselect ID,
    chip erase with Data# polling, 256-byte write-buffer programs, verify).
    programmer/sim/usb_cart_model.py models the engine + flash for tests;
    test_e2e.sh now covers r1, r2 via the Mega, and r2 over USB.
    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
2026-10-02 r2: netlist generator for the FPGA + USB-C board
    r2/hw/gen_r2.py builds circuit.netlist.json (68 parts, 116 nets) from the
    datasheet-checked pin tables in docs/r2-pinouts.json and the shared FPGA pin
    map (r2/hw/fpga_pins.json): GW1N-LV4QN88, S29GL064N (x8), FM28V020, 3x
    74LVCH245 + SN74LVC8T245, CH347F + 8 MHz crystal, USB-C + USBLC6, 48 MHz
    oscillator, B5819W OR-ing, XC6206 3.3 V + ME6211 1.2 V, MPN/LCSC on every
    assembled part. Tall symbols use a pin x offset no other symbol uses, so the
    fixed-grid generated schematic cannot merge nets (the r1 bug).
    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
2026-10-02 r2 netlist: prove the generated schematic has no merged nets; fix ERC pin types
    fab_pcb draws every pin stub 5.08 mm to the left (even for right-side pins)
    on a fixed grid, and KiCad joins anything touching a wire. gen_r2.py now
    simulates that geometry exactly, checks every net pair for touching points
    or segments, and searches component order / symbol width / pin-row parity
    until there are none (this reproduced the 6 merged pairs fabdesk reported).
    LDO outputs are power_out, diode-fed inputs and signal pins passive, so each
    powered net has exactly one driver.
    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
2026-10-02 mech: DMG cartridge shell model and board fit check
    - mech/shell.py: parametric CadQuery shell (back half, standard front, USB-C front for r2),
    exported to STEP/STL; dims in mech/dims.py, sourced in docs/gb-cart-mechanical.md
    - mech/fit_check.py: checks any .kicad_pcb against the shell (outline, holes, fingers,
    component zone, heights, thickness, USB-C mouth) -> mech/out/fit.json
    - mech/std_board.py: OEM-style reference outline + GB_Cart_Edge_32_DMG footprint
    - mech/fit.html: fit report with top view, stack-up and 3D viewer
    r1 and r2 currently fail (56 mm wide vs 53.2 mm cavity, no screw-tube hole,
    fingers 0.5 mm from the edge); the reference outline passes.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
    [dmg_reference.kicad_pcb, pcb_std_outline.step, pcb_std_outline.stl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]
2026-10-02 r1.1 / r2.1: move both boards to the DMG cartridge outline (WIP, routing)
    - r2/hw/layout_dmg.py: r2.1 placement on the OEM outline (51.4 x 61, notch,
    shell holes) with a courtyard / zone / hole checker; USB-C centred on the
    top edge, FPGA decoupling at the QFN corners to keep a fan-out ring
    - r2/hw/gen_r2.py, scripts/gen.py: outline polygon, shell holes, DMG edge
    footprint; r2 clearance 0.1 mm for the QFN-88 pad pitch
    - r2/hw/power_vias.py, fab_api.py: GND/3V3 plane vias and In1/In2 planes via
    fabdesk native_edit_transaction
    - mech/shell.py: USB-C opening through the back half too (shell_back_usb),
    opening centred on J2; fit_check/fit.html allow J2 past the top rib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
    [pcb_std_outline.step, shell_back.step, shell_back_usb.step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]
2026-10-02 r1.1: DMG cartridge outline, re-routed, DRC clean
    r1 (56 x 49.5 mm) did not fit a cartridge shell. r1.1 is the same circuit on
    the OEM outline (51.4 x 61 mm, finger tongue, lock notch, shell holes),
    1.0 mm thick, edge fingers 1.5 mm above the board edge.
    - Re-placed inside the shell component zone and re-routed in fabdesk with
    Freerouting (134/134), copper keep-outs around both shell holes
    - DRC 0 errors / 0 unconnected (silkscreen warnings only); fit check passes
    (PLCC-32 height warning)
    - JLC gerbers / CPL, renders and README updated
    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
    [board.kicad_pcb, board.kicad_sch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]
2026-10-02 r2.1: QFN pad-pitch DRC rules, 0.15 mm clearance, plane-safe re-route setup (WIP)
    - r2/hw/board.kicad_dru: 0.1 mm pad clearance only inside U1/U10, 0.1 mm neck-downs
    - gen_r2.py: back to 0.15 mm board clearance; copies the .kicad_dru into the project
    - power_vias.py --no-zones; fab_api.hole_keepouts for the shell holes
    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
2026-10-02 r2.1: route at 0.1 mm clearance (JLC 4-layer 0.09) after the 0.15 mm run stalled on QFN pad pitch
    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
2026-10-02 r2.1: FPGA + USB-C board on the DMG outline, routed, DRC clean
    - r2/board/: KiCad project (4 layers, 1.0 mm, 51.4 x 61 mm DMG outline),
    GND plane on In1, 3V3 on In2, signals on F.Cu/B.Cu (Freerouting via
    fabdesk route_run, 181/181), DRC 0 errors / 0 unconnected / 0 parity
    - fit check: r1.1 and r2.1 fit; mech/fit.html now compares them with the
    old r1 / r2
    - JLC gerbers (4 layers) / BOM / CPL; jlc_export.py and sync_fields.py take
    BOARD_DIR
    - 3D models for the r2 parts (KiCad library; generated HRO USB-C, SG210 for
    the 2.5x2.0 oscillator) and renders
    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
    [ArtInChip_QFN-88-1EP_10x10mm_P0.4mm_EP6.74x6.74mm.step, Crystal_SMD_3225-4Pin_3.2x2.5mm.step, D_SOD-123.step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]
2026-10-02 JLCPCB: live part check and order estimate for r1.1 and r2.1
    - scripts/jlc_check.py: every BOM line against JLC's parts library (stock, Basic/Extended,
    price breaks, MPN); scripts/jlc_cost.py: PCB quote + parts + assembly fees
    - docs/jlcpcb-pricing.md rewritten for both boards (2026-10-02 snapshot)
    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

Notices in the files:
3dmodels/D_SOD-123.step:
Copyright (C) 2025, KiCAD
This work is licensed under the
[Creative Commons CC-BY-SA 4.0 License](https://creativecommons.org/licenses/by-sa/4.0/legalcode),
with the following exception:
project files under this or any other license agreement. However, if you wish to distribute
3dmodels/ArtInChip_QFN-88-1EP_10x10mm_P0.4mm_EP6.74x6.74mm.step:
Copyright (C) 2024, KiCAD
